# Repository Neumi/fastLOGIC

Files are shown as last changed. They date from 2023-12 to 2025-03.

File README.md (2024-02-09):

# fastLOGIC! open-source (industrial) logic controller
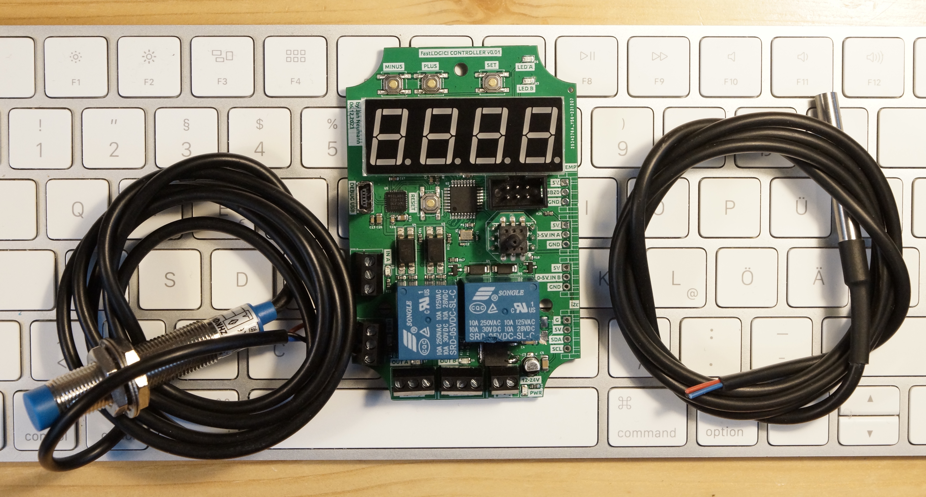
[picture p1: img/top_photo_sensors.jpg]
banner image


### An affordable Arduino-based board designed for straightforward (industrial) logic control, ideal for building small-scale automation and control solutions.
FastLOGIC! is designed to cater to the automation needs of various applications, especially those with modest logic requirements. Its purpose is to streamline smaller projects by eliminating the need for excessive error-prone breadboarding while retaining flexibility and adaptability.

Use cases could be one of these: 
- a programmable fridge controller
- water level-dependent pump controller
- a timer that is triggered by a button
- an actuator that activates and moves to an end stop upon receiving a triggering input
- some sensor data you need to display
- a water level sensor/alarm
- you get the idea

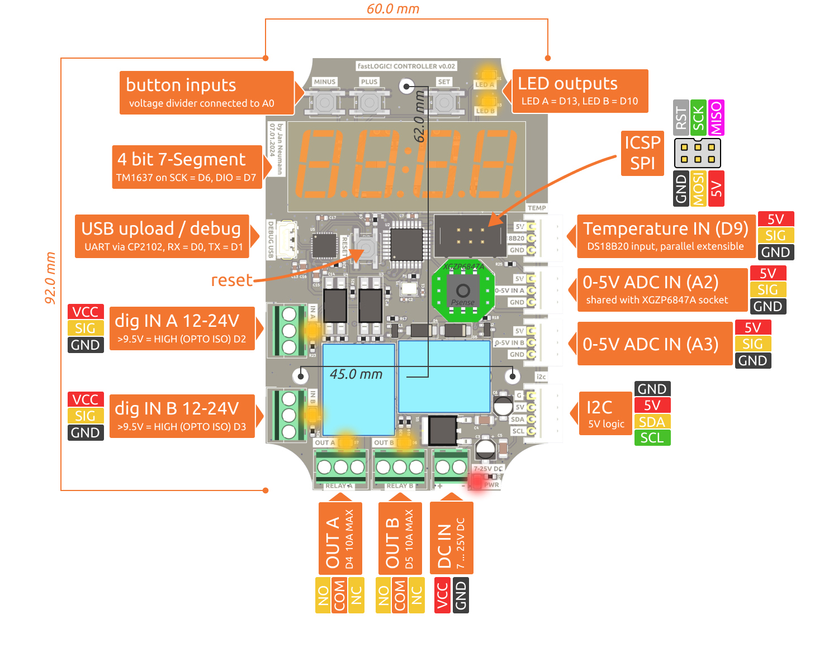
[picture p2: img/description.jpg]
description image


# Software

The Arduino [library](https://github.com/Neumi/fastLOGIC/tree/main/software/library/fastLOGIC) can be used to get started. A few example sketches show what fastLOGIC! is capable of, how to read sensor data and how to write outputs to the LEDs and relays.

The library covers most cases, but if you want to write or read directly from or to the pins:
```cpp
// fastLOGIC! pin mapping
DIGITAL_IN_A = D2;
DIGITAL_IN_B = D3;
RELAY_A_OUT = D5;
RELAY_B_OUT = D4;
TM1637_SCK = D6;
TM1637_DIO = D7;
DS18B20_DATA = D9;
LED_B_OUT = D10;
LED_A_OUT = D13;
VOLTAGE_SENS_IN = A0;
BUTTONS_IN = A1;
ANALOG_IN_A = A2;
ANALOG_IN_B = A3;
```

If you want to use the **7-segment display**, use this [library](https://github.com/avishorp/TM1637).

The part numbers in the KiCAD files are LCSC part numbers. This means you can order directly from JLCPCB using the manufacturing files in the [production folder](https://github.com/Neumi/fastLOGIC/tree/main/hardware/version001/fastLOGIC/production).
I typically opt for SMT parts exclusively due to the high cost associated with THT assembly and also because not all the required parts are readily available in stock.

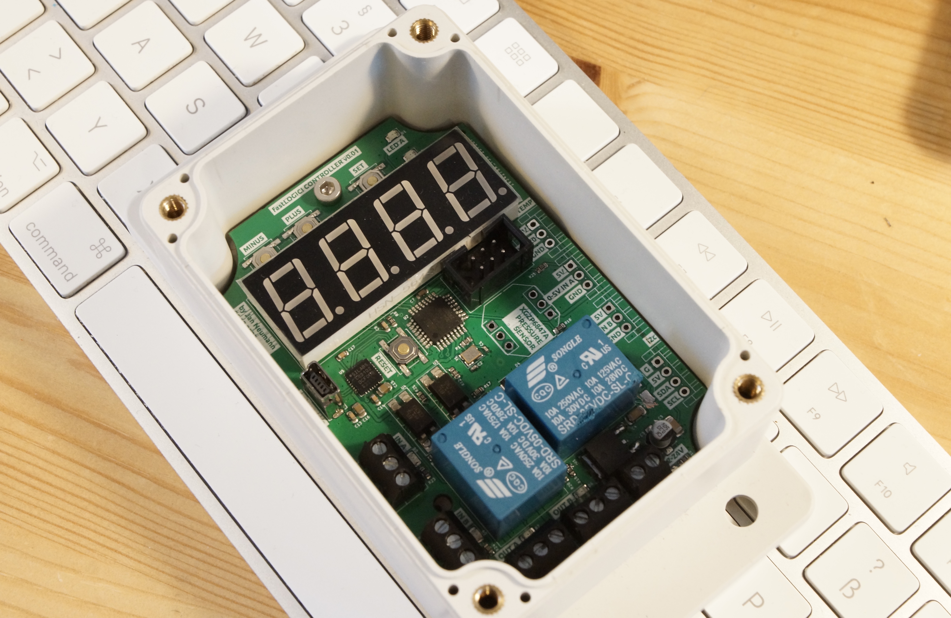
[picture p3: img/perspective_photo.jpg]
perspective photo


# Hardware
The placement is largely self-explanatory. If you find yourself uncertain, you can refer to the images provided below or utilize the 3D view feature in KiCAD for further clarification.

###  The only hardware parts you need:
- [relais 5V](https://de.aliexpress.com/item/1005006065653383.html)
- [4-bit Common Anode Display](https://de.aliexpress.com/item/1005006101748128.html)
- [JST connectors 3pin + 4pin](https://de.aliexpress.com/item/4000120545240.html)
- [Screw terminals 2pin + 3pin](https://de.aliexpress.com/item/1005005194957825.html)
- [USB connector Type A](https://de.aliexpress.com/item/1005004679855929.html)
- [Case](https://de.aliexpress.com/item/32760647473.html)
- an [ISP](https://de.aliexpress.com/item/1005006164091737.html) or Arduino in ISP mode to burn the Bootloader
- three 5mm (M3) screws

### Optional:
- [XGZP6847a pressure sensor](https://de.aliexpress.com/item/1005003768236942.html)
- [High-pressure sensor](https://de.aliexpress.com/item/1005005510454084.html)
- [DS18B20 temperature sensor](https://de.aliexpress.com/item/1005005973956237.html)

## Assembly
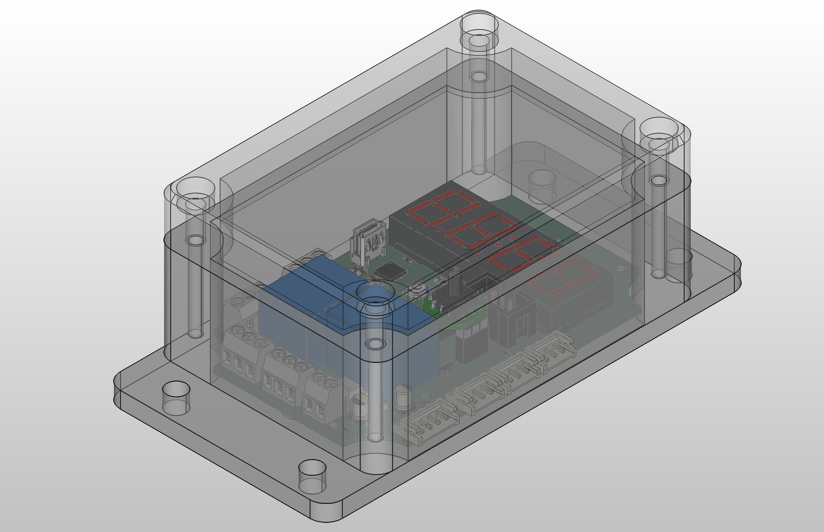
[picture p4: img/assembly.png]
assembly case 3D


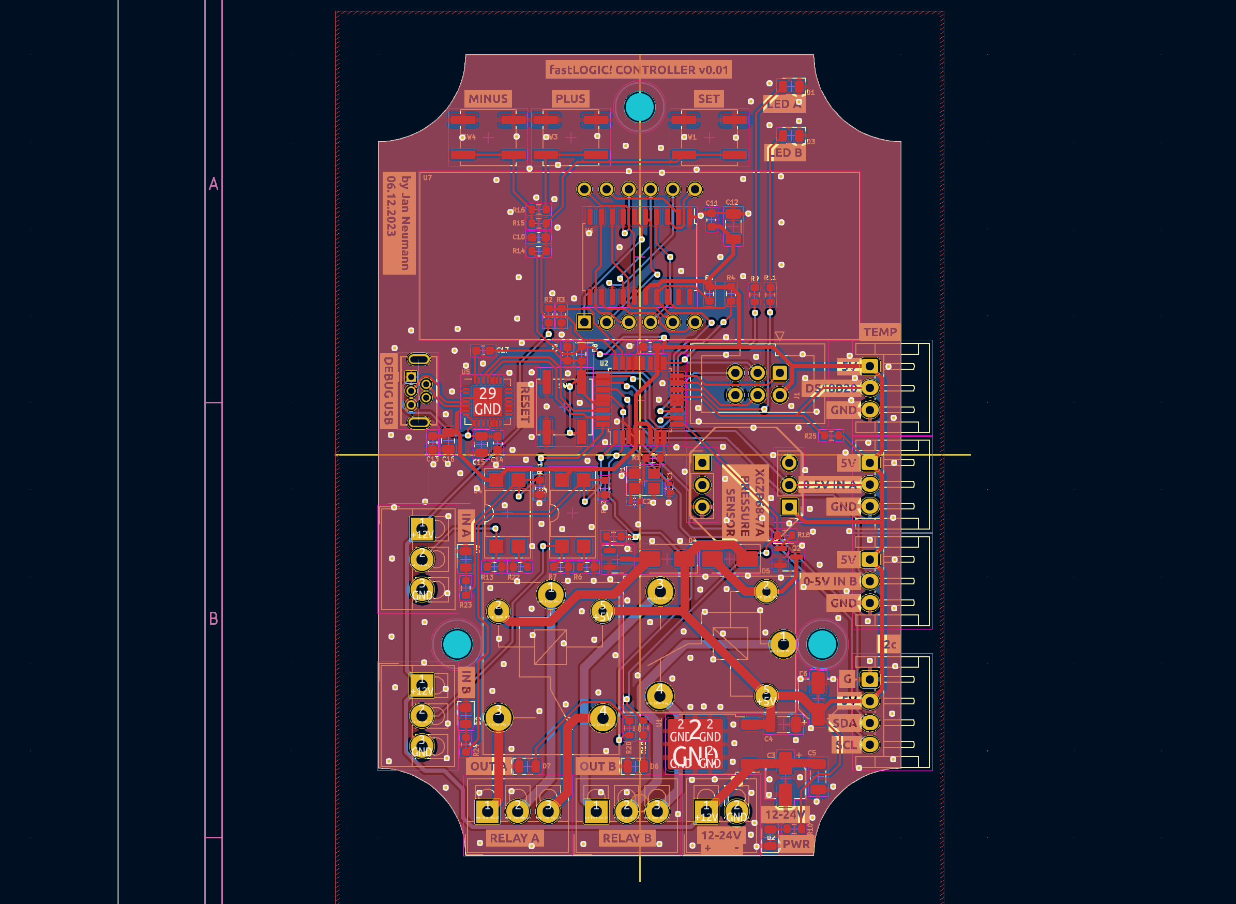
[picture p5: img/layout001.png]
layout screenshot


## Video:
LINK TO VIDEO (https://www.youtube.com/watch?v=e4RQ7bSTlrE)

Follow the project on [hackaday.io](https://hackaday.io/project/194762-fastlogic-open-source-industrial-logic-control)!

### Enjoy the project, but keep in mind:
* **The project is still under development and is currently in the prototype stage! Keep an eye out for updates!**
* **This also implies that not all functions are guaranteed to work flawlessly and may not be entirely safe**
* **Avoid unsupervised usage in a production environment. Utilize at your own risk**
* **Ensure input voltage is between the range of 12 to 25V. (Currently lacking reverse polarity protection)**
* **Do not use the relay to switch mains voltage! It's suitable only for low voltage and currents below 5A**

### Happy building + coding!

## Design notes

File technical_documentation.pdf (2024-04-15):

FastLOGIC! industrial controller technical documentation

FastLOGIC! industrial controller hardware revision 0.02_07.01.2024 document version 1.0

### Description

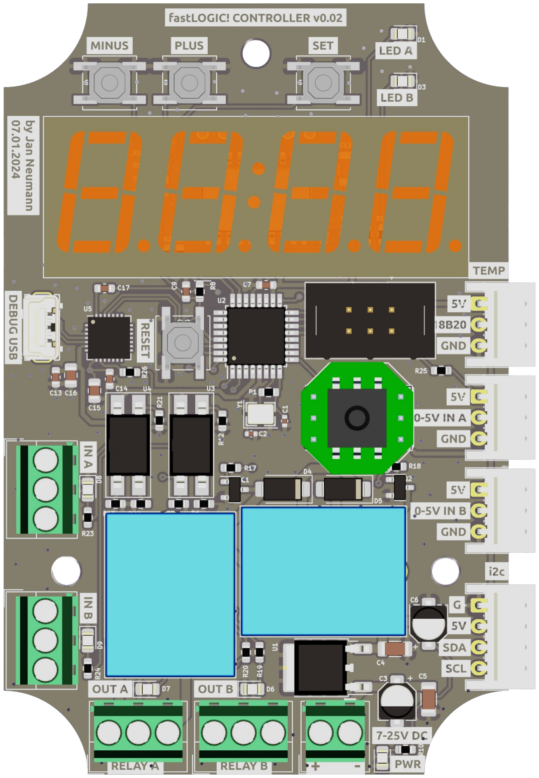
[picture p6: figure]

FastLOGIC! is a development board to get started with simple automation tasks. It could be used for experimentation and education but also for small permanent automation installations. A number of standard and easy-to-use in- and outputs give the user fast access to the world of automation.
Use cases could range from a simple sensor data display to complex logic operations and decision-making based on sensor inputs to switch outputs.

### Target users

Makers, Hobbyists, Engineers

FastLOGIC! v0.02

### Features

- ATMega328p microcontroller
- AVR CPU at 16MHz
- 32KB Flash
- 2KB SRAM
- 1KB EEPROM
- Power
- 7-25V DC supply
- 5V logic and sensor voltage
- 34mA idle current at 12V
- Peripherals I/O
- USB / UART
- 2x digital input
- 3x button input
- 2x orange LED output
- 4-Bit 7-Segment red display
- DS18b20 temperature sensor
- XGZP6847A pressure sensor socket
- 2x 10-Bit 0-5V analog input
- I2C interface
- Serial Peripheral Interface (SPI)
- 2x relay output
- Watchdog timer
- Electrical connectors
- Mini USB vertical
- 3.5mm screw terminal for relays and digital inputs (3-pin)
- 3.5mm screw terminal for power (2-pin)
- JST EH sensor inputs (3-pin)
- JST EH i2C (4-pin)
- XGZP6847A pressure sensor socket
- 6-pin ICSP programming header
- Physical properties
- PCB only: 90 * 60 * 19 mm (L * W * H), 43g
- With Housing: 100 * 68 * 50 mm (L * W * H), 98g
- M3 mounting: triangle 45 * 62 mm (A * h)
- Software
- Programmable via Arduino IDE
- FastLOGIC! library

Page 2

### 1 Application Examples and Use Cases

For educational, hobby, and professional users FastLOGIC! provides an easy start to automation as the well-known programming language C++ and the Arduino IDE can be used out of the box. Everything that runs on an Arduino UNO runs on FastLOGIC! as well.
Standard sensors and interfaces make FastLOGIC! easily adaptable and expandable.

Possible use cases could be:
- display to read sensor data
- a timer that switches an output for a defined time after a button press
- RPM counter using an induction sensor
- water level sensor using the XGZP6847A pressure sensor
- temperature controller using DS18b20 sensors with EEPROM set value data memory

### 2 Ratings

Symbol | Description | Min | Typ | Max | Unit
Vin | Input supply voltage on screw terminal | 7.0 | 12.0 | 25.0 | V
U | Current draw at 12V input voltage | 0.04 | - | 0.3 | A
P | Power consumption at 12V | 0.4 | - | 3.6 | W
Vusb | USB supply voltage | 4.5 | 5.0 | 5.5 | V
Urel | Switchable relay current | - | - | 10 | A
Irel | Switchable relay voltage | - | - | 30 | V
Vtrig | Digital input A and B trigger voltage | - | 9.5 | - | V
Vanalog | Analog input voltage | -0.5 | - | 5.5 | V
Tmax | Safe temperature range | -40 | - | +85 | °C

NOTE: In extreme temperatures, EEPROM, voltage regulator, analog reference, and the crystal oscillator, might not work as expected!

Page 3

### 3 Functional Overview

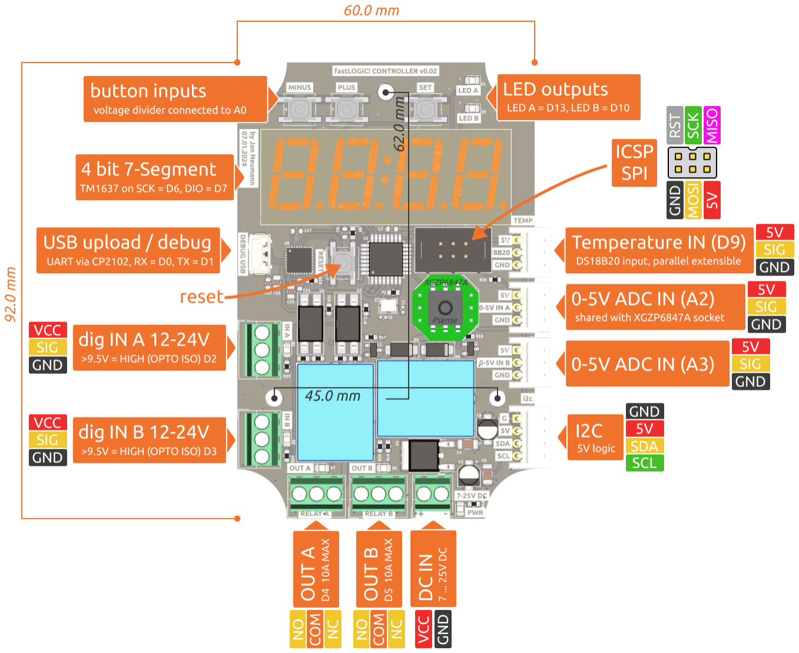
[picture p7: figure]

Figure 1: Functional overview of inputs, outputs, dimensions, and pinouts

### 4 Getting Started Connect

To program the board using the Arduino IDE, use a Mini USB cable to connect it to the computer. The cable also provides 5V power to run the board.

NOTE: The computer must provide enough current to power all connected sensors!

Page 4

### IDE Setup

The board behaves just like an Arduino UNO board. Therefore select Ardunino UNO as the development platform. The board has to be “Arduino Uno”. Select the corresponding serial port for your board.

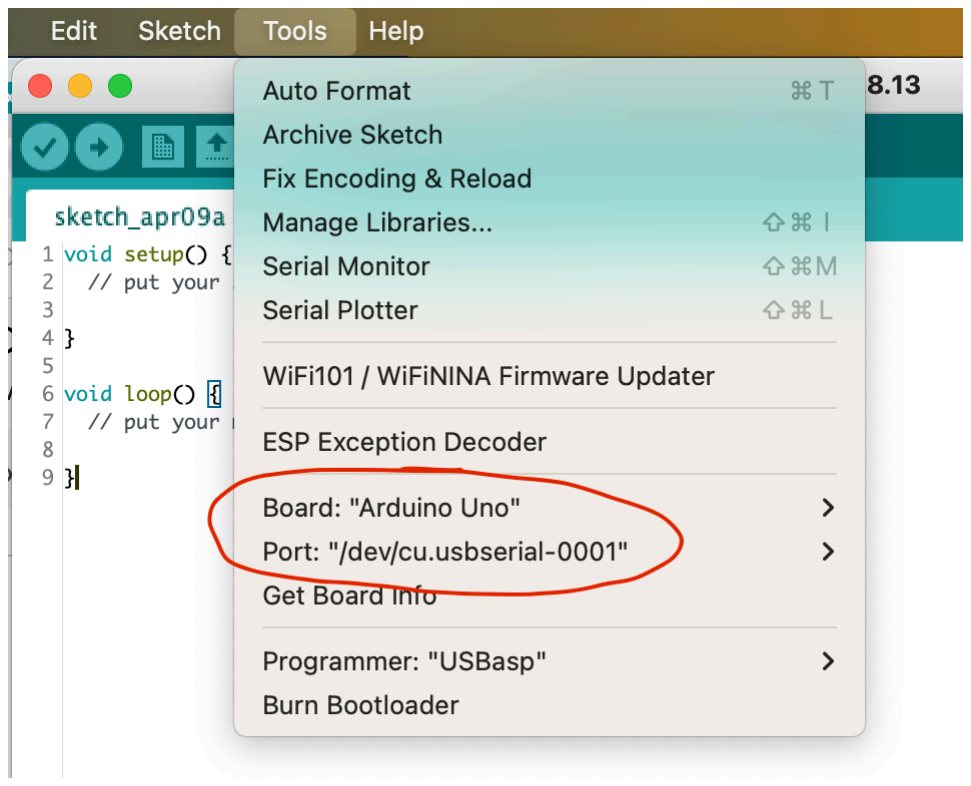
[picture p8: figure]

Figure 2: Arduino IDE board settings for uploading code to FastLOGIC!

Use the upload button to upload the code.

Note: Press the reset button on FastLOGIC! while the code is uploading. Otherwise, the upload will fail.

### Programming

Use the examples from the GitHub repository to get started. It helps you use the ports, sensors, and relays with simple OOP methods.
You can use all the standard functionalities, the Arduino UNO supports like millis, sleep, EEPROM, etc. Inputs can be read using digitalRead and analogRead. The relays can be switched using digitalWrite on the corresponding pins.

Page 5

### Pin mapping

Each functionality is connected to a certain pin on the ATMega328. The pin mapping shows each pin and its associated function.

Page 6

Pin name | Pin number | Description
RX | D0 | directly connected to CP2102 USB / Serial chip
TX | D1 | directly connected to CP2102 USB / Serial chip
DIGITAL_IN_A | D2 | reads HIGH when input A HIGH (>9.5V)
DIGITAL_IN_B | D3 | reads HIGH when input B HIGH (>9.5V)
RELAY_B_OUT | D4 | output HIGH drives the relay B
RELAY_A_OUT | D5 | output HIGH drives the relay A
TM1637_SCK | D6 | TM1637 display driver clock pin
TM1637_DIO | D7 | TM1637 display driver data pin
NC | D8 | not connected
DS18B20_DATA | D9 | DS18B20 temperature sensor data pin (pulled HIGH by 4.7k)
LED_B_OUT | D10 | HIGH enables LED B
LED_A_OUT | D13 | HIGH enables LED A
VOLTAGE_SENS_IN | A0 | reads Vin via 1 : 4.45 voltage divider (Vin 25V MAX!)
BUTTONS_IN | A1 | reads buttons: SET: <20; MINUS: >25 & <45; PLUS: >320 & <470
ANALOG_IN_A | A2 | reads analog IN A and XGZP6847A pressure sensor
ANALOG_IN_B | A3 | reads analog IN B 0-5V (5.5V MAX!)
I2C_SDA | A4 | I2C bus data pin SDA
I2C_SCL | A5 | I2C bus clock pin SCL

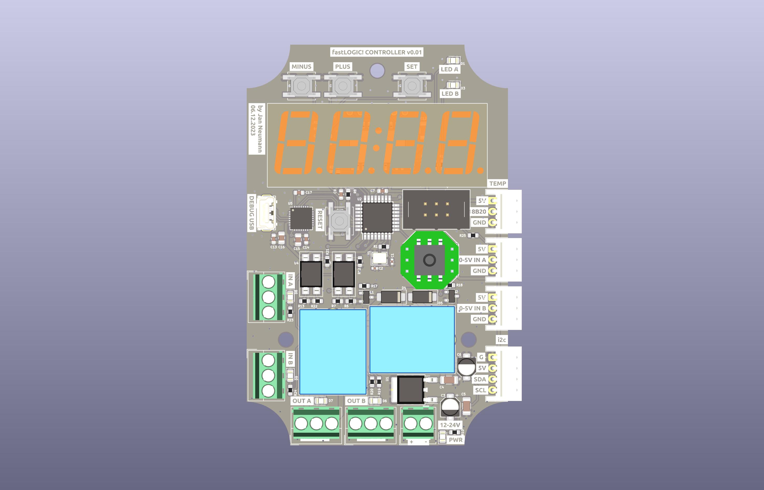
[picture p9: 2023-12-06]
img/board001.png

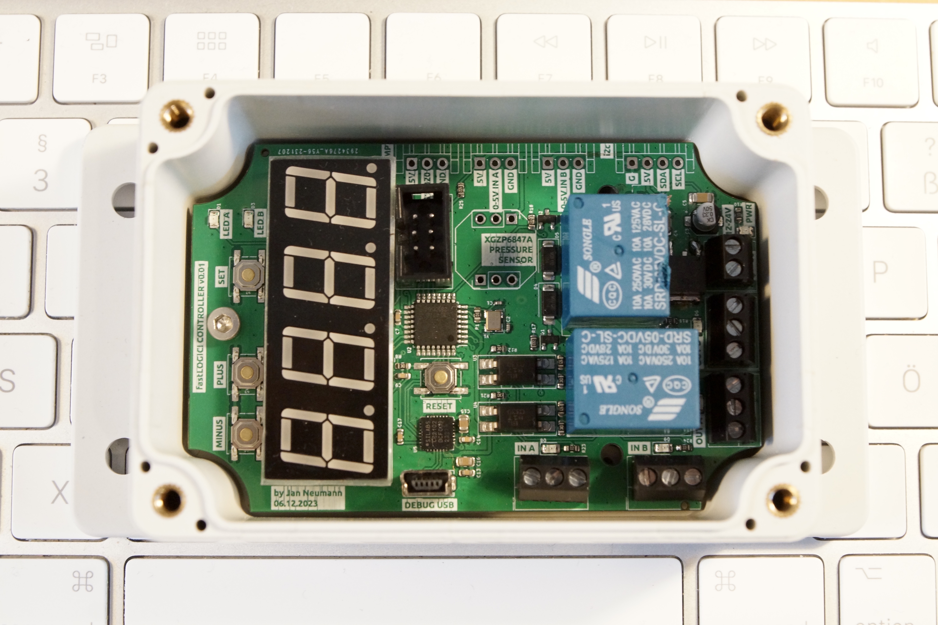
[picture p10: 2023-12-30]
img/top_photo.jpg

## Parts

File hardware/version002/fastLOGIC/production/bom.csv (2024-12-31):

Designator | Footprint | Quantity | Value | LCSC Part #
BT1 | BatteryHolder_Keystone_1060_1x2032 | 1 | Battery_Cell | C70377
C1, C12 | 1206 | 2 | C100uF | C15008
C10, C11, C13, C14, C15, C16, C17, C19, C2, C23, C24, C27, C31, C7, C8, C9 | 0603 | 16 | C100nF | C14663
C18, C4, C5 | 1206 | 3 | C100nF | C24497
C20, C21 | 0402 | 2 | C22pF | C1555
C22, C6 | 1206 | 2 | C47uF | C96123
C28 | 1206 | 1 | C1nF | C9196
C29, C30 | 0402 | 2 | C18pF | C1549
C3 | CP_Elec_4x5.4 | 1 | C_330nF | C264238
C32, C45 | 0805 | 2 | C10uF | C15850
C33 | 0402 | 1 | C10nF | C15195
C34 | 0603 | 1 | C22nF | C21122
C35 | 0402 | 1 | C4.7uF | C23733
C36 | 0603 | 1 | C10nF | C57112
C37, C38 | 0402 | 2 | C6.8nF | C1542
C39, C40, C41, C42, C43, C44 | 0402 | 6 | C100nF | C307331
D1 | 0805 | 1 | LED_A | C2297
D10 | 0805 | 1 | LED_SPD | C2296
D11 | 0805 | 1 | LED_3.3V_PWR | C2296
D12 | 0805 | 1 | LED_DUP | C2296
D13 | 0805 | 1 | LED_PC13 | C84256
D14 | 0805 | 1 | LED_OUT_C | C2296
D15, D4, D5 | D_SMA | 3 | D | C22452
D16 | 0805 | 1 | LED_C | C2297
D17 | 0805 | 1 | LED_D | C2297
D18 | 0805 | 1 | TX | C2297
D19 | 0805 | 1 | RX | C2297
D2 | 0805 | 1 | LED_PWR | C84256
D3 | 0805 | 1 | LED_B | C2297
D6, D9 | 0805 | 2 | LED_OUT_B | C2296
D7, D8 | 0805 | 2 | LED_OUT_A | C2296
H1, H2, H3, H5 | MountingHole_3.2mm_M3_DIN965 | 4 | MH
J1 | JST_EH_S3B-EH_1x03_P2.50mm_Horizontal | 1 | 0-5V_ANALOG_IN_A | C157928
J10 | LCD_GMG12864-06D | 1 | LCD
J11, J19, J24 | PinHeader_1x02_P2.54mm_Vertical | 3 | GND
J12, J18, J20 | Jack_3.5mm_PJ320E_Horizontal | 3 | AudioJack4_Ground
J13 | JST_EH_S3B-EH_1x03_P2.50mm_Horizontal | 1 | 0-5V_ANALOG_IN_B | C157928
J14 | TerminalBlock_4Ucon_1x03_P3.50mm_Vertical | 1 | RELAY_OUT_B | C2997510
J15 | TerminalBlock_4Ucon_1x03_P3.50mm_Vertical | 1 | RELAY_OUT_A | C2997510
J16 | TerminalBlock_4Ucon_1x03_P3.50mm_Vertical | 1 | RELAY_OUT_C | C2997510
J17 | USB_Mini-B_Tensility_54-00023_Vertical | 1 | USB_B_Mini | C6331167
J2 | TerminalBlock_4Ucon_1x02_P3.50mm_Vertical | 1 | RS485 | C2997509
J21 | microSD_HC_Hirose_DM3AT-SF-PEJM5 | 1 | Micro_SD_Card_Det_Hirose_DM3AT | C114218
J22, J25, J6 | PinHeader_1x02_P2.54mm_Vertical | 3 | VIN
J23 | RJ45_Hanrun_HR911105A_Horizontal | 1 | HR911105A | C12074
J26 | JST_EH_B4B-EH-A_1x04_P2.50mm_Vertical | 1 | UART | C157925
J3 | JST_EH_S3B-EH_1x03_P2.50mm_Horizontal | 1 | DS18B20 | C157928
J4 | TerminalBlock_4Ucon_1x02_P3.50mm_Vertical | 1 | 12-24V | C2997509
J5 | JST_EH_S4B-EH_1x04_P2.50mm_Horizontal | 1 | I2C | C157925
J8 | TerminalBlock_4Ucon_1x03_P3.50mm_Vertical | 1 | 12-24V_IN_A | C2997510
J9 | TerminalBlock_4Ucon_1x03_P3.50mm_Vertical | 1 | 12-24V_IN_B | C2997510
JP1, JP2 | PinHeader_1x02_P2.54mm_Vertical | 2 | termination_jumper
K1, K2, K3 | Relay_SPDT_SANYOU_SRD_Series_Form_C | 3 | SANYOU_SRD_Form_C | C35449
L1 | 0805 | 1 | L600OHM | C1017
Q1, Q2, Q3, Q6 | SOT-23 | 4 | MMBT5551L | C2145
Q4, Q5 | SOT-23 | 2 | BSS138 | C112239
R1, R10, R11, R19, R2, R20, R23, R24, R44, R45, R53, R54, R63, R64, R65, R66, R9 | 0603 | 17 | R330 | C23138
R12, R13, R14, R15, R16, R21, R26, R31, R33, R34, R36, R37, R39, R4, R5, R59, R7 | 0603 | 17 | R10k | C25804
R17, R18, R3, R60 | 0603 | 4 | R2.2k | C4190
R22, R6 | 0603 | 2 | R470 | C23179
R25 | 0603 | 1 | R4.7k | C23162
R27 | 0805 | 1 | R120 | C17437
R28, R38 | 0402 | 2 | R1M | C26083
R29, R30, R32, R35, R48, R55, R56, R57, R58, R61, R62, R8 | 0603 | 12 | R1k | C21190
R40, R41, R42, R43 | 0603 | 4 | R33 | C23140
R46 | 0603 | 1 | R12K4 | C22865
R47 | 0603 | 1 | R10 | C22859
R49, R50, R51, R52 | 0603 | 4 | R49.9 | C23185
SW1 | SW_Push_1P1T_NO_CK_KSC7xxJ | 1 | SET | C318884
SW3 | SW_Push_1P1T_NO_CK_KSC7xxJ | 1 | PLUS | C318884
SW4 | SW_Push_1P1T_NO_CK_KSC7xxJ | 1 | MINUS | C318884
SW5 | SW_Push_1P1T_NO_CK_KSC7xxJ | 1 | RST | C318884
TP1 | TestPoint_Pad_D2.0mm | 1 | PA4
TP2 | TestPoint_Pad_D2.0mm | 1 | SCL2
TP3 | TestPoint_Pad_D2.0mm | 1 | RX
TP4 | TestPoint_Pad_D2.0mm | 1 | TX
TP5, TP8 | TestPoint_Pad_D2.0mm | 2 | GND
TP6, TP9 | TestPoint_Pad_D2.0mm | 2 | 3.3V
TP7 | TestPoint_Pad_D2.0mm | 1 | SDA2
U1 | TO-252-2 | 1 | LM78M05_TO252 | C58069
U10 | SOT-223-3_TabPin2 | 1 | AMS1117-3.3 | C6186
U13 | LQFP-48_7x7mm_P0.5mm | 1 | W5500 | C32843
U2 | XGZP6847A | 1 | ~
U3, U4 | DIP-4_W8.89mm_SMDSocket_LongPads | 2 | EL817 | C106900
U6 | LQFP-100_14x14mm_P0.5mm | 1 | STM32F407VGTx | C12345
U8 | SOP-8_3.9x4.9mm_P1.27mm | 1 | MAX485E | C481667
U9 | QFN-28-1EP_5x5mm_P0.5mm_EP3.35x3.35mm | 1 | CP2102N-A01-GQFN28 | C6568
Y2 | Crystal_SMD_5032-2Pin_5.0x3.2mm | 1 | Crystal | C115962
Y3 | Crystal_SMD_3225-4Pin_3.2x2.5mm | 1 | Crystal_25MHz | C9006

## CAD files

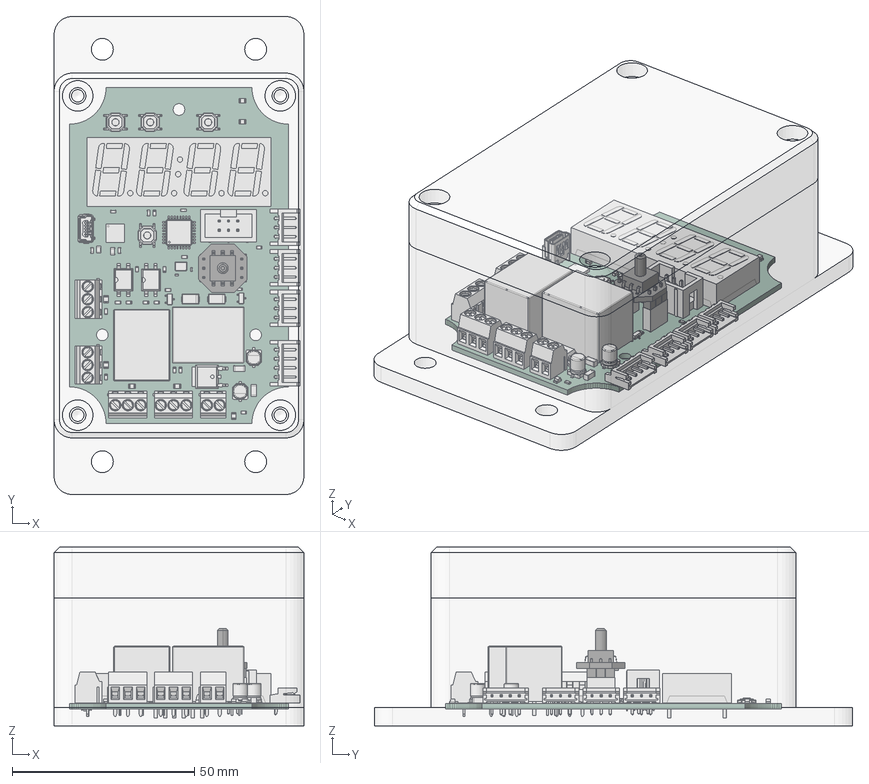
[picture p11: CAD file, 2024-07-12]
hardware/full_assembly.FCStd
68.5 x 131.0 x 49.0 mm
case
PCB
lid

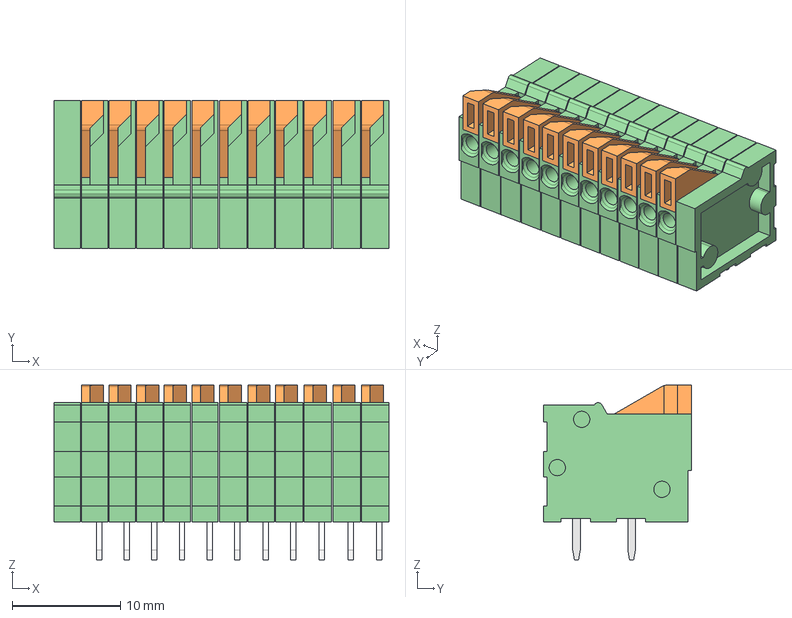
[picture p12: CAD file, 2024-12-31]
hardware/version002/fastLOGIC/3d_files/TERMINAL_BLOCKS_141r/DG141R-11-2.54.step
30.9 x 13.6 x 16.1 mm
Тело_28 - Копия_3:4 x 5
Тело_28 - Копия_3:3 x 5
Тело_28 - Копия_3:2 x 5
Тело_28 - Копия_3:1 x 5
Тело_11 - Внешняя модель_11:2 x 2
Тело_12 - Внешняя модель_12:2 x 2
Тело_20 - Внешняя модель_20:2 x 2
Тело_14 - Внешняя модель_14:2 x 2

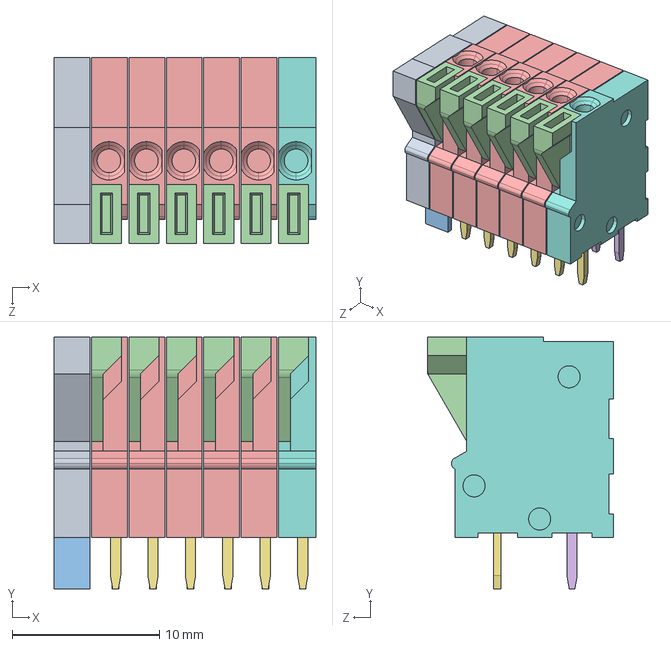
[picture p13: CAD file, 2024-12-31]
hardware/version002/fastLOGIC/3d_files/TERMINAL_BLOCKS_141v/DG141V-5-2.54.STEP
17.8 x 17.1 x 12.6 mm

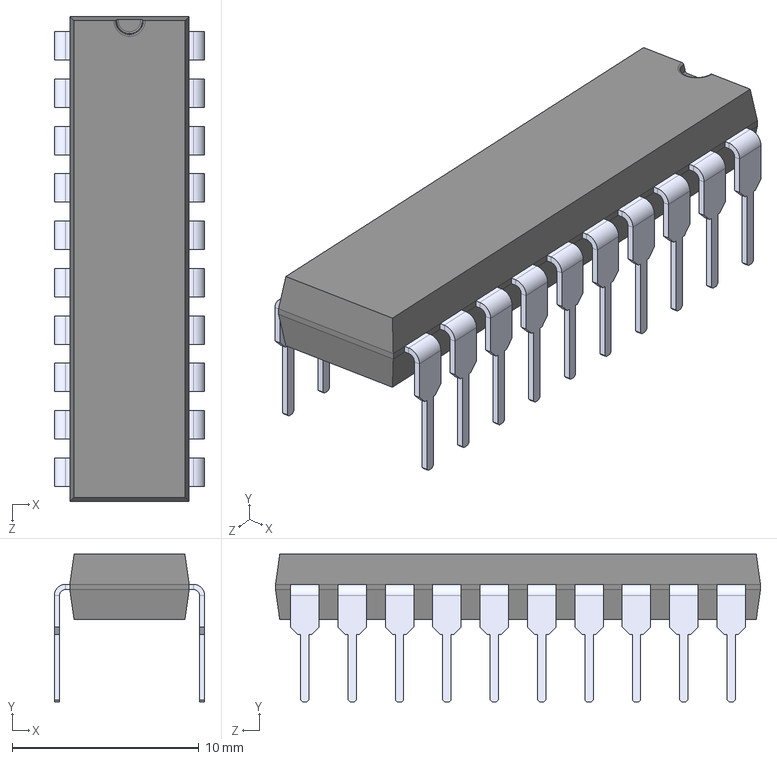
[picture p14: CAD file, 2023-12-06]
hardware/version002/fastLOGIC/components/TM1637/TM1637.step
8.06 x 7.91 x 26.0 mm

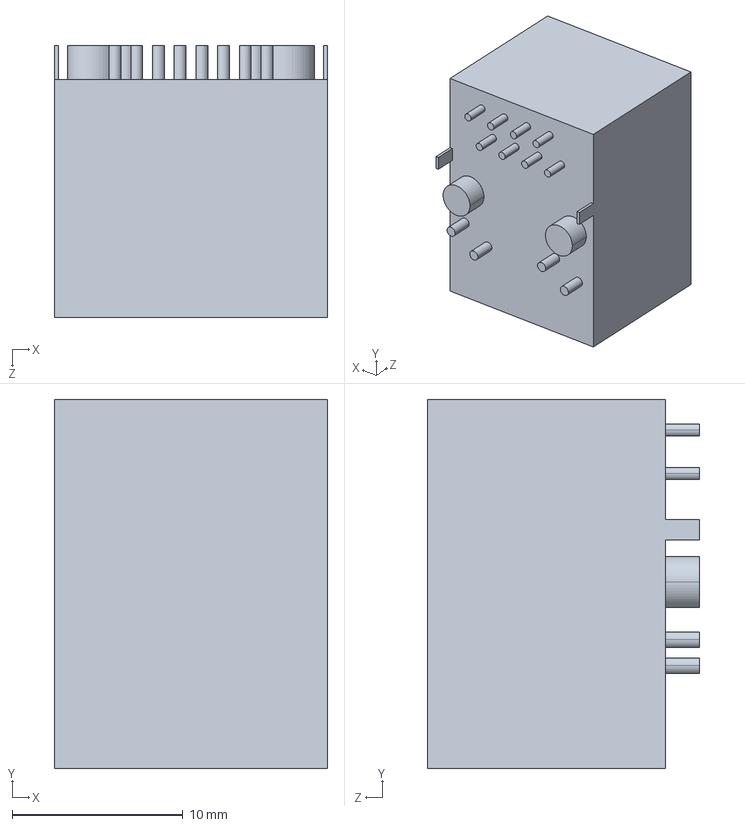
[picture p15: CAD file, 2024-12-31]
hardware/version002/fastLOGIC/3d_files/HANRUN.STEP
16.0 x 21.6 x 15.9 mm

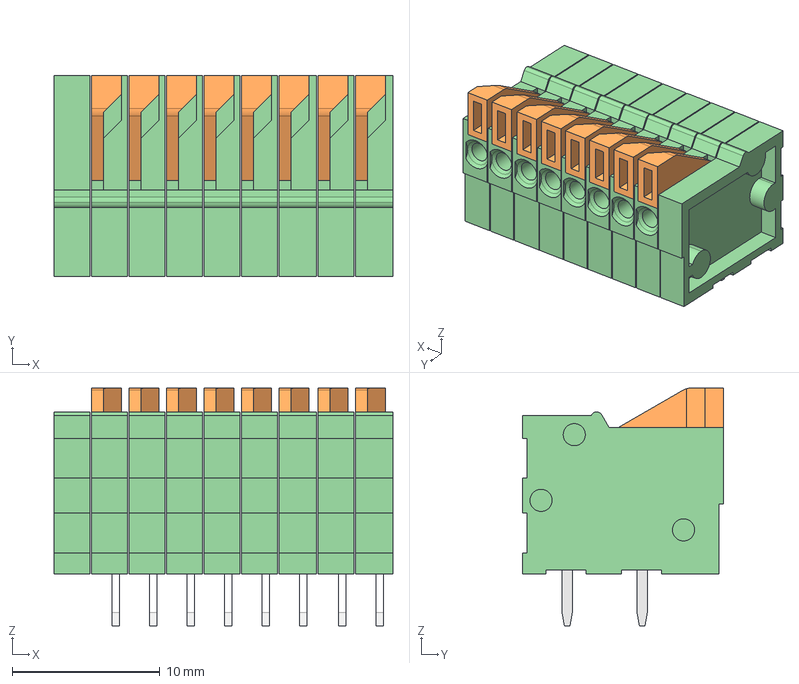
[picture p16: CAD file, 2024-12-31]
hardware/version002/fastLOGIC/3d_files/TERMINAL_BLOCKS_141r/DG141R-8-2.54.step
23.0 x 13.6 x 16.1 mm
Тело_1 - Внешняя модель_1:2 x 2
Тело_11 - Внешняя модель_11:2 x 2
Тело_12 - Внешняя модель_12:2 x 2
Тело_6 - Внешняя модель_6:2 x 2
Тело_19 - Внешняя модель_19:2 x 2
Тело_20 - Внешняя модель_20:2 x 2
Тело_14 - Внешняя модель_14:2 x 2
Тело_13 - Внешняя модель_13:2 x 2

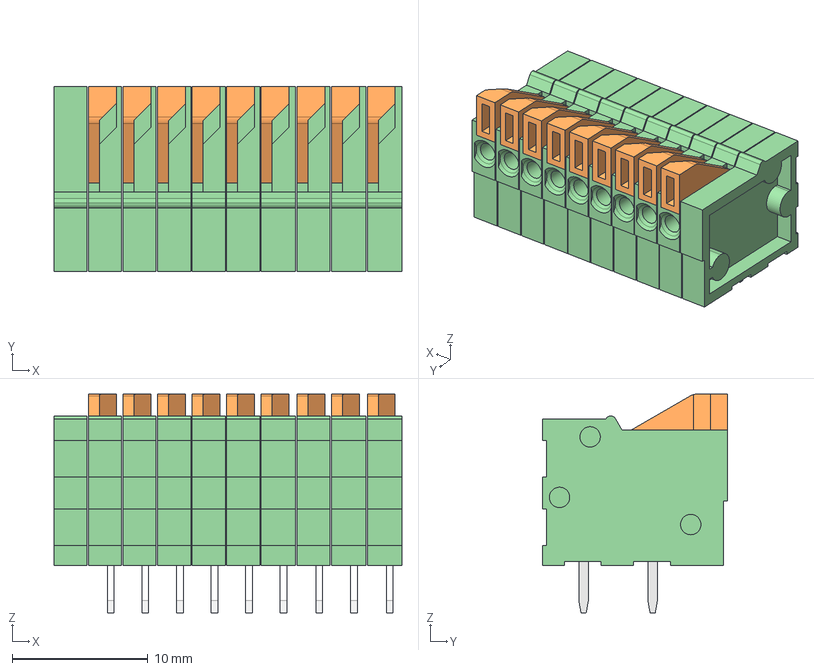
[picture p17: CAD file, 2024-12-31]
hardware/version002/fastLOGIC/3d_files/TERMINAL_BLOCKS_141r/DG141R-9-2.54.step
25.6 x 13.6 x 16.1 mm
Тело_1 - Внешняя модель_1:3 x 3
Тело_6 - Внешняя модель_6:3 x 3
Тело_13 - Внешняя модель_13:3 x 3
Тело_19 - Внешняя модель_19:3 x 3
Тело_11 - Внешняя модель_11:2 x 2
Тело_12 - Внешняя модель_12:2 x 2
Тело_20 - Внешняя модель_20:2 x 2
Тело_14 - Внешняя модель_14:2 x 2

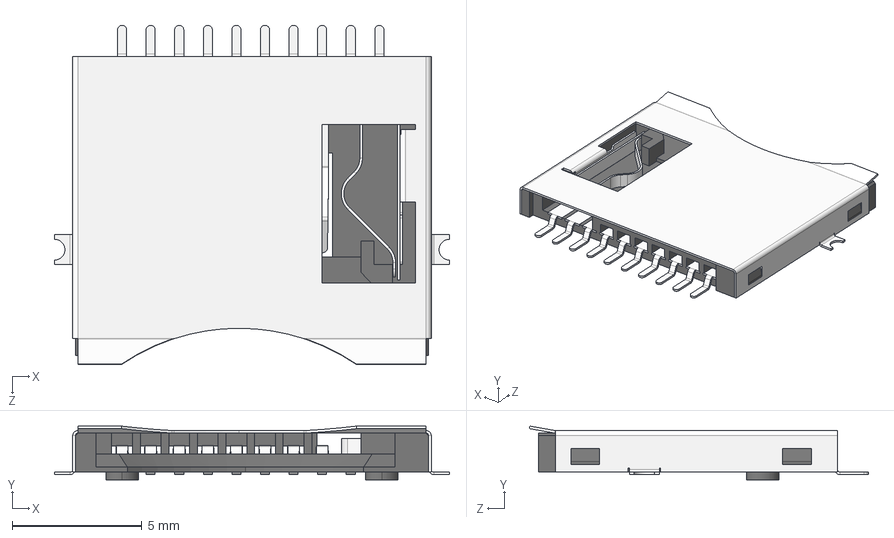
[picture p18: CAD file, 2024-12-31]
hardware/version002/fastLOGIC/3d_files/SocketMicroSD.STEP
15.2 x 2.07 x 13.1 mm
Base
Terminal 01 x 8
Terminal 02
Terminal 03
Socket Cover

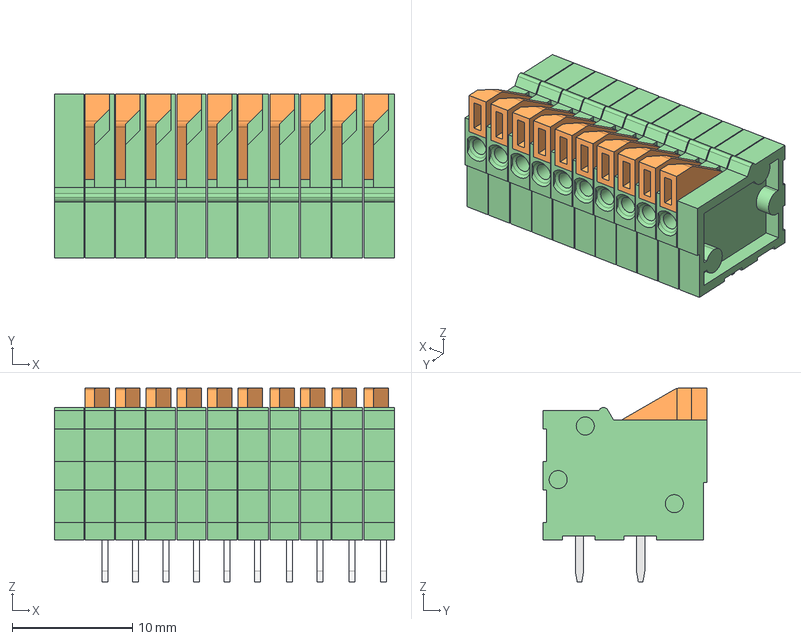
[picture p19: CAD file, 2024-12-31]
hardware/version002/fastLOGIC/3d_files/TERMINAL_BLOCKS_141r/DG141R-10-2.54.step
28.2 x 13.6 x 16.1 mm
Тело_27 - Копия_2:4 x 4
Тело_27 - Копия_2:3 x 4
Тело_27 - Копия_2:2 x 4
Тело_27 - Копия_2:1 x 4
Тело_11 - Внешняя модель_11:2 x 2
Тело_12 - Внешняя модель_12:2 x 2
Тело_20 - Внешняя модель_20:2 x 2
Тело_14 - Внешняя модель_14:2 x 2

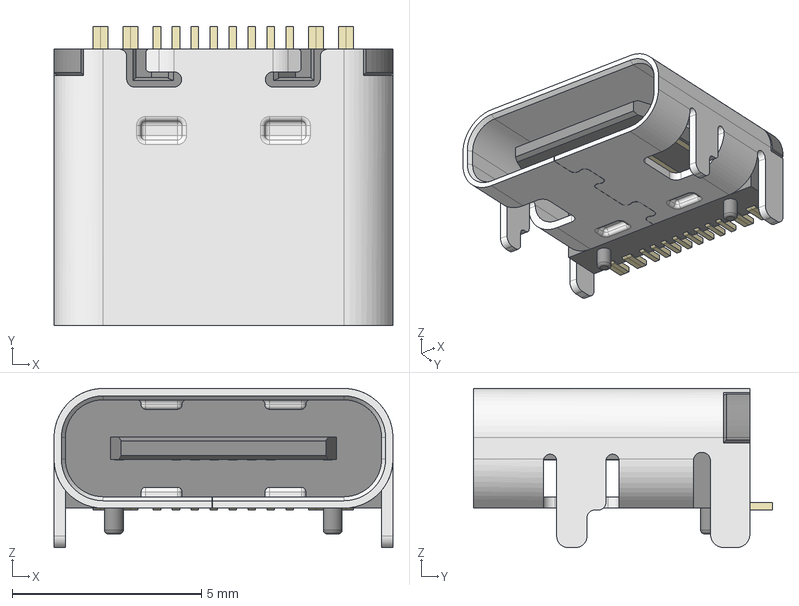
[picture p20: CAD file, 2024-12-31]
hardware/version002/fastLOGIC/3d_files/HRO_TYPE-C-31-M-12.step
8.95 x 7.90 x 4.20 mm

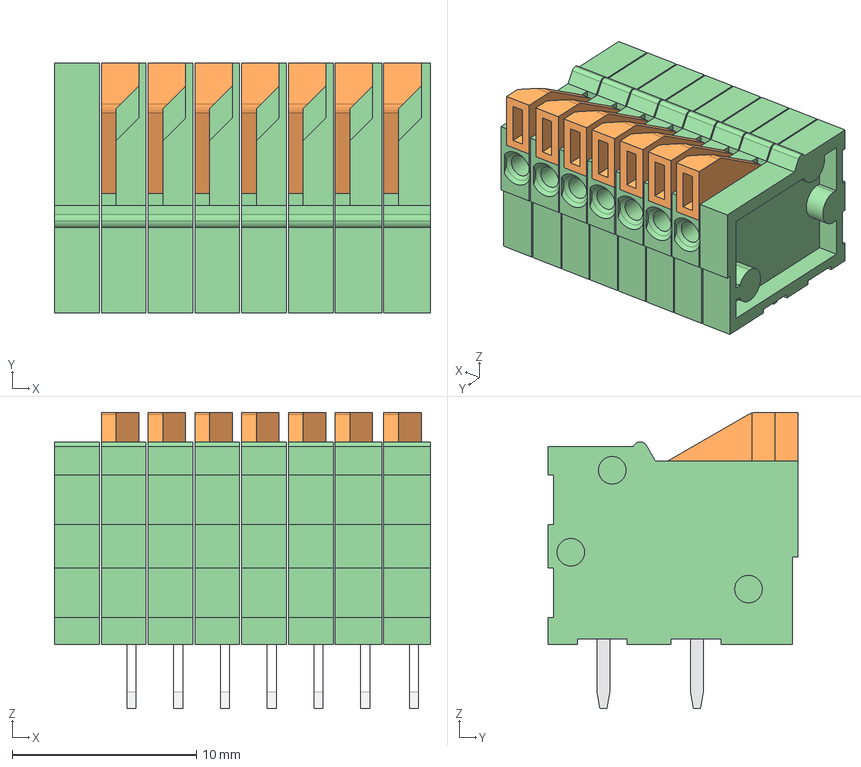
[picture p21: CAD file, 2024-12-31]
hardware/version002/fastLOGIC/3d_files/TERMINAL_BLOCKS_141r/DG141R-7-2.54.step
20.4 x 13.6 x 16.1 mm
Тело_1 - Внешняя модель_1:2 x 2
Тело_6 - Внешняя модель_6:2 x 2
Тело_13 - Внешняя модель_13:2 x 2
Тело_19 - Внешняя модель_19:2 x 2

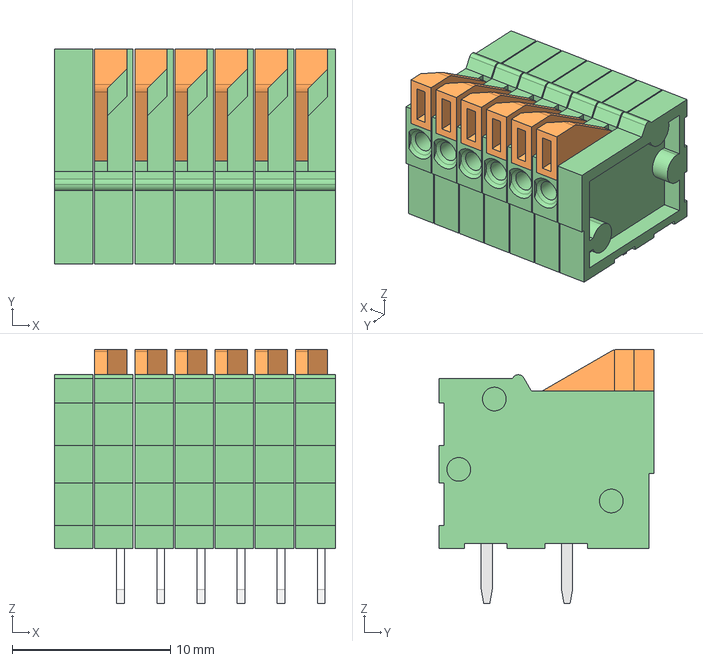
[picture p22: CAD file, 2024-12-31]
hardware/version002/fastLOGIC/3d_files/TERMINAL_BLOCKS_141r/DG141R-6-2.54.step
17.8 x 13.6 x 16.1 mm

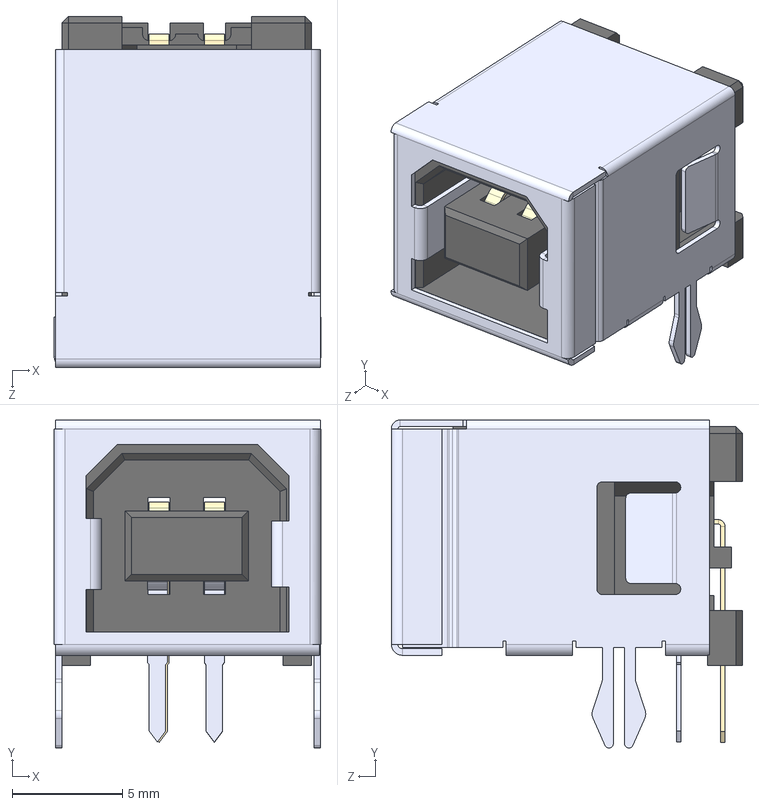
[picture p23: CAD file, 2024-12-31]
hardware/version002/fastLOGIC/3d_files/USB_B.STEP
12.1 x 14.8 x 15.9 mm
BlackBase
MetalShape
TermLong x 2
TermShort x 2

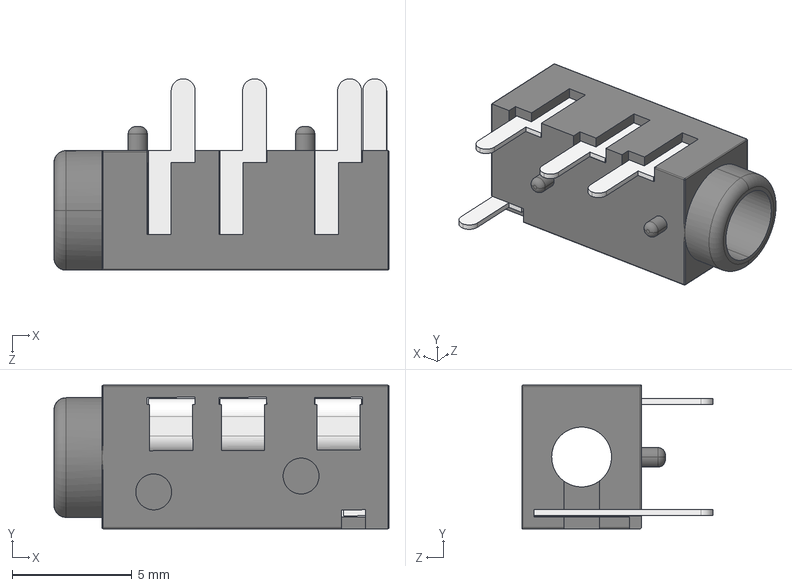
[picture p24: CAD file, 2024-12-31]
hardware/version002/fastLOGIC/3d_files/PJ320A.STEP
14.0 x 6.00 x 8.00 mm
PJ320A
PJ320A-Pin x 3
PJ320A-Pin-B

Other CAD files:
hardware/version002/fastLOGIC/3d_files/TERMINAL_BLOCKS_141v/DG141V-4-2.54.STEP
hardware/version002/fastLOGIC/3d_files/TERMINAL_BLOCKS_141v/DG141V-6-2.54.STEP
hardware/version002/fastLOGIC/3d_files/TERMINAL_BLOCKS_141v/DG141V-2-2.54.STEP
hardware/version002/fastLOGIC/3d_files/TERMINAL_BLOCKS_141v/DG141V-3-2.54.STEP
hardware/version002/fastLOGIC/3d_files/GMG12864-06D.step
hardware/version002/fastLOGIC/3d_files/HR911105A.step
hardware/version002/fastLOGIC/3d_files/Mini-B USB Vertical.stp
hardware/version002/fastLOGIC/3d_files/PCB Terminal Block 2 DEG381-3.5.step
hardware/version002/fastLOGIC/3d_files/PCB Terminal Block 3 DEG381-3.5.step
hardware/version002/fastLOGIC/3d_files/TERMINAL_BLOCKS_141r/DG141R-12-2.54.step
hardware/version002/fastLOGIC/3d_files/TERMINAL_BLOCKS_141r/DG141R-2-2.54.step
hardware/version002/fastLOGIC/3d_files/TERMINAL_BLOCKS_141r/DG141R-3-2.54.step
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

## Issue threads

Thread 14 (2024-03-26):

rework settings menu

Neumi, 2024-03-26:
Change settings menu 3-add-library-support-for-settings-menu so that it follows Arduino Class schema

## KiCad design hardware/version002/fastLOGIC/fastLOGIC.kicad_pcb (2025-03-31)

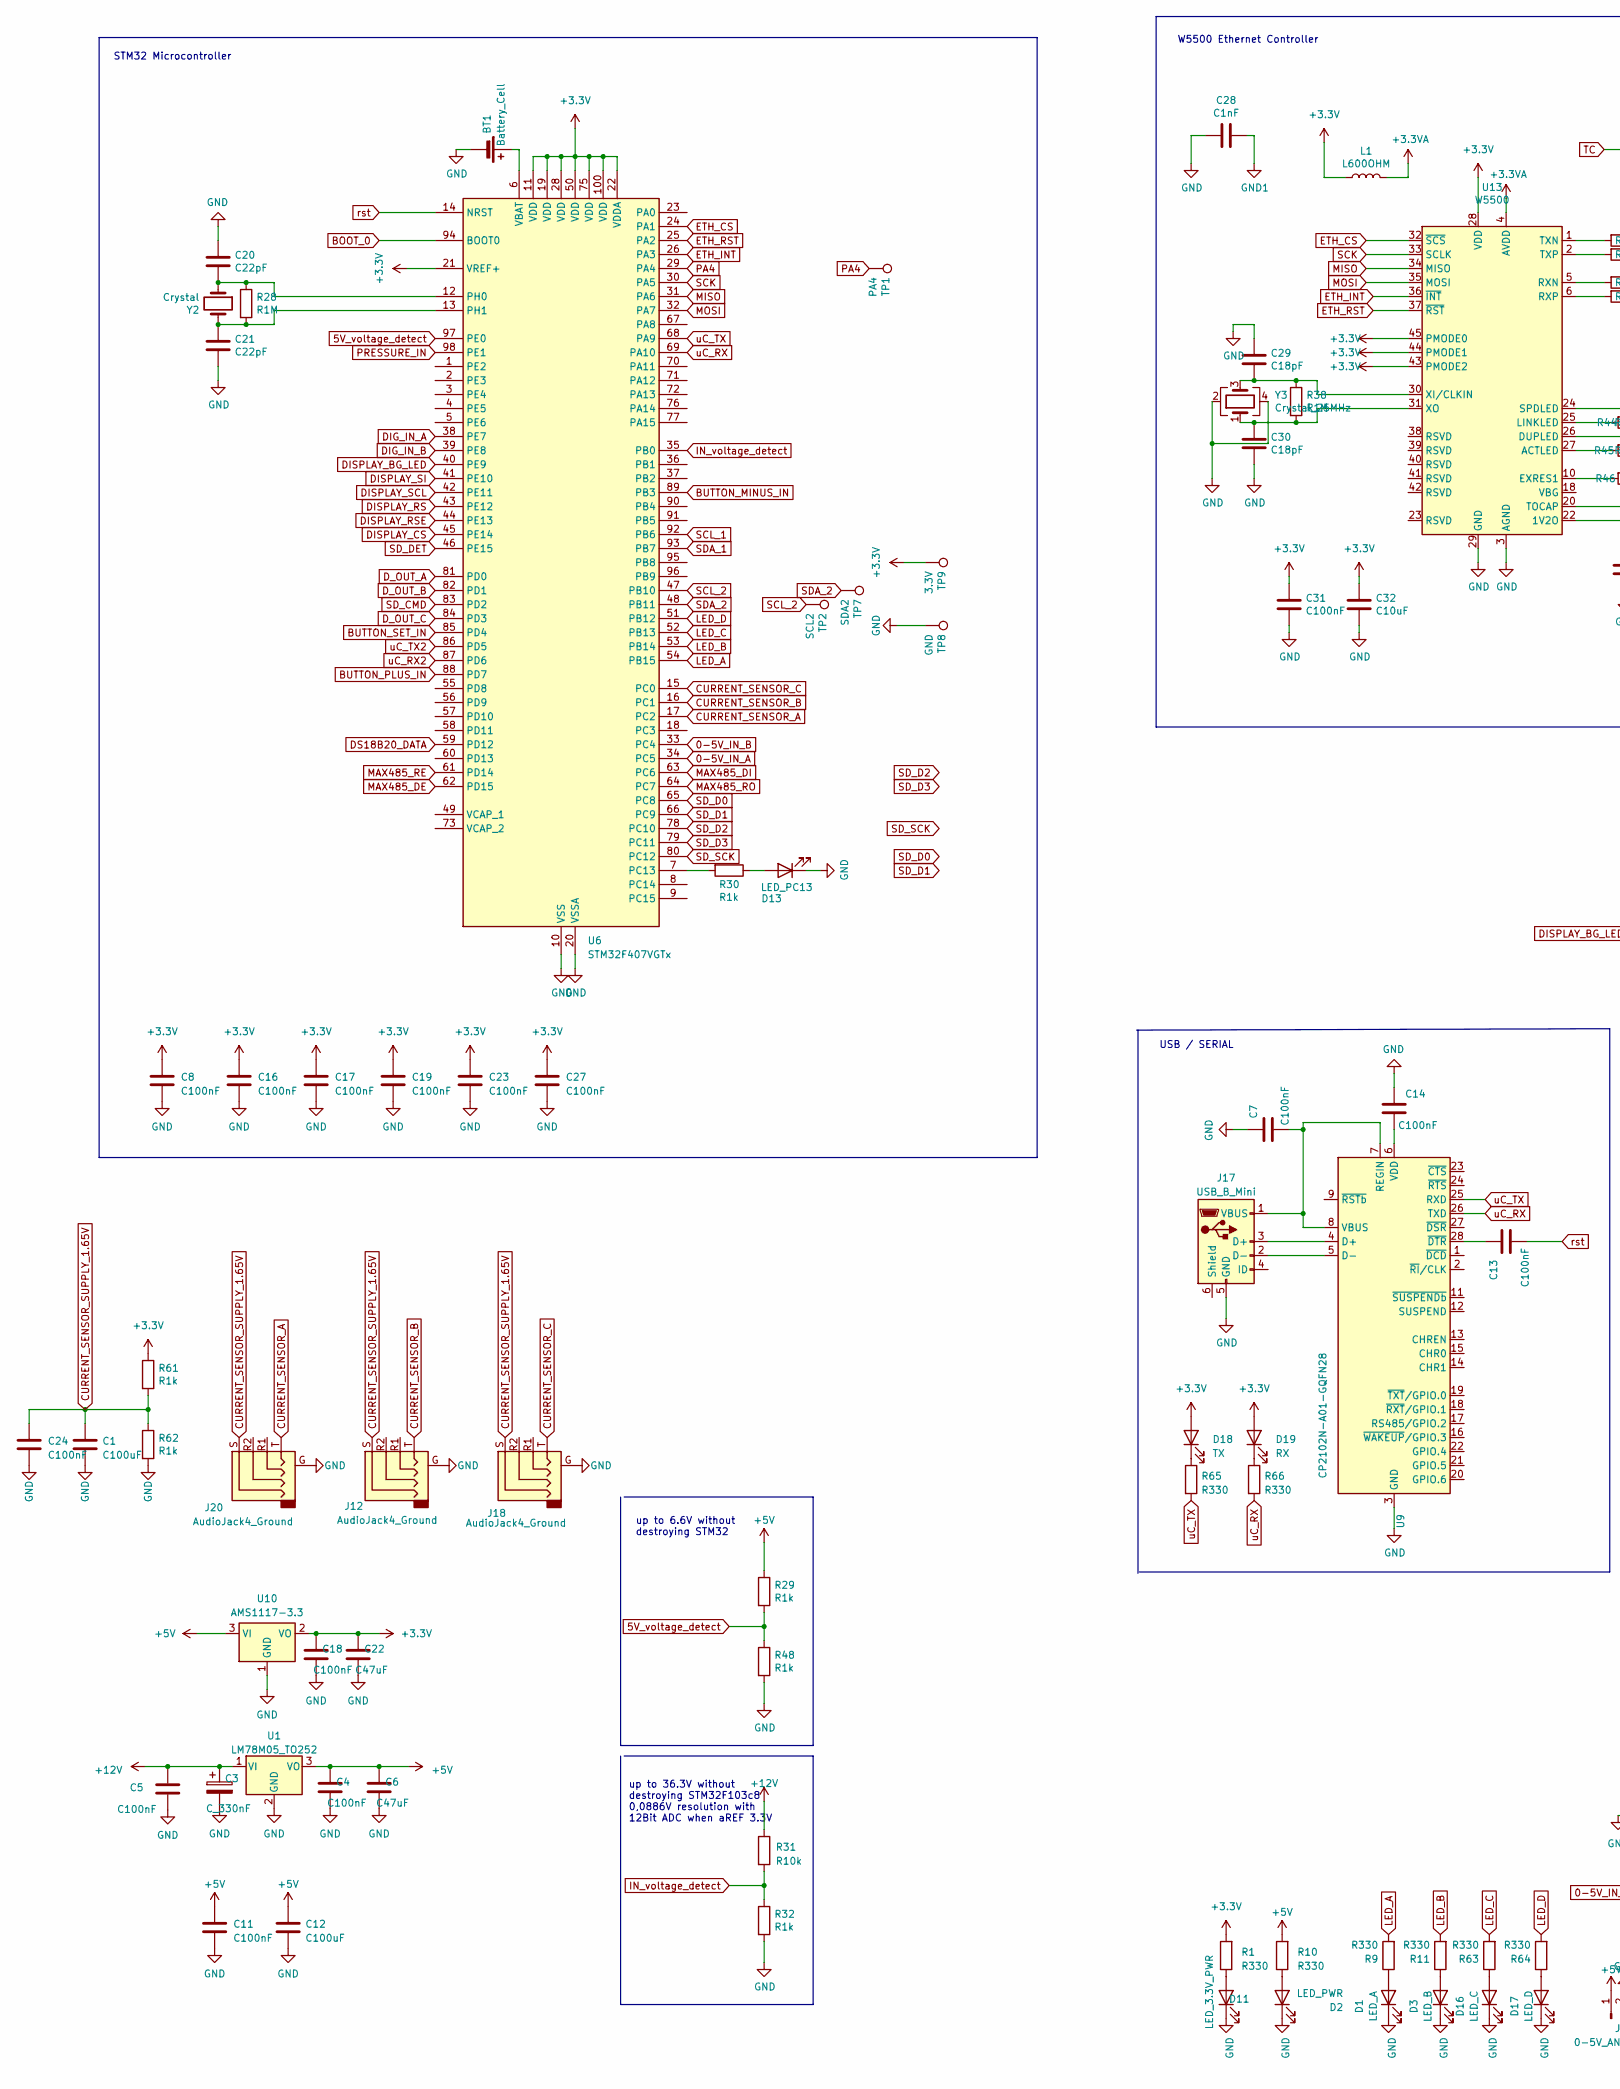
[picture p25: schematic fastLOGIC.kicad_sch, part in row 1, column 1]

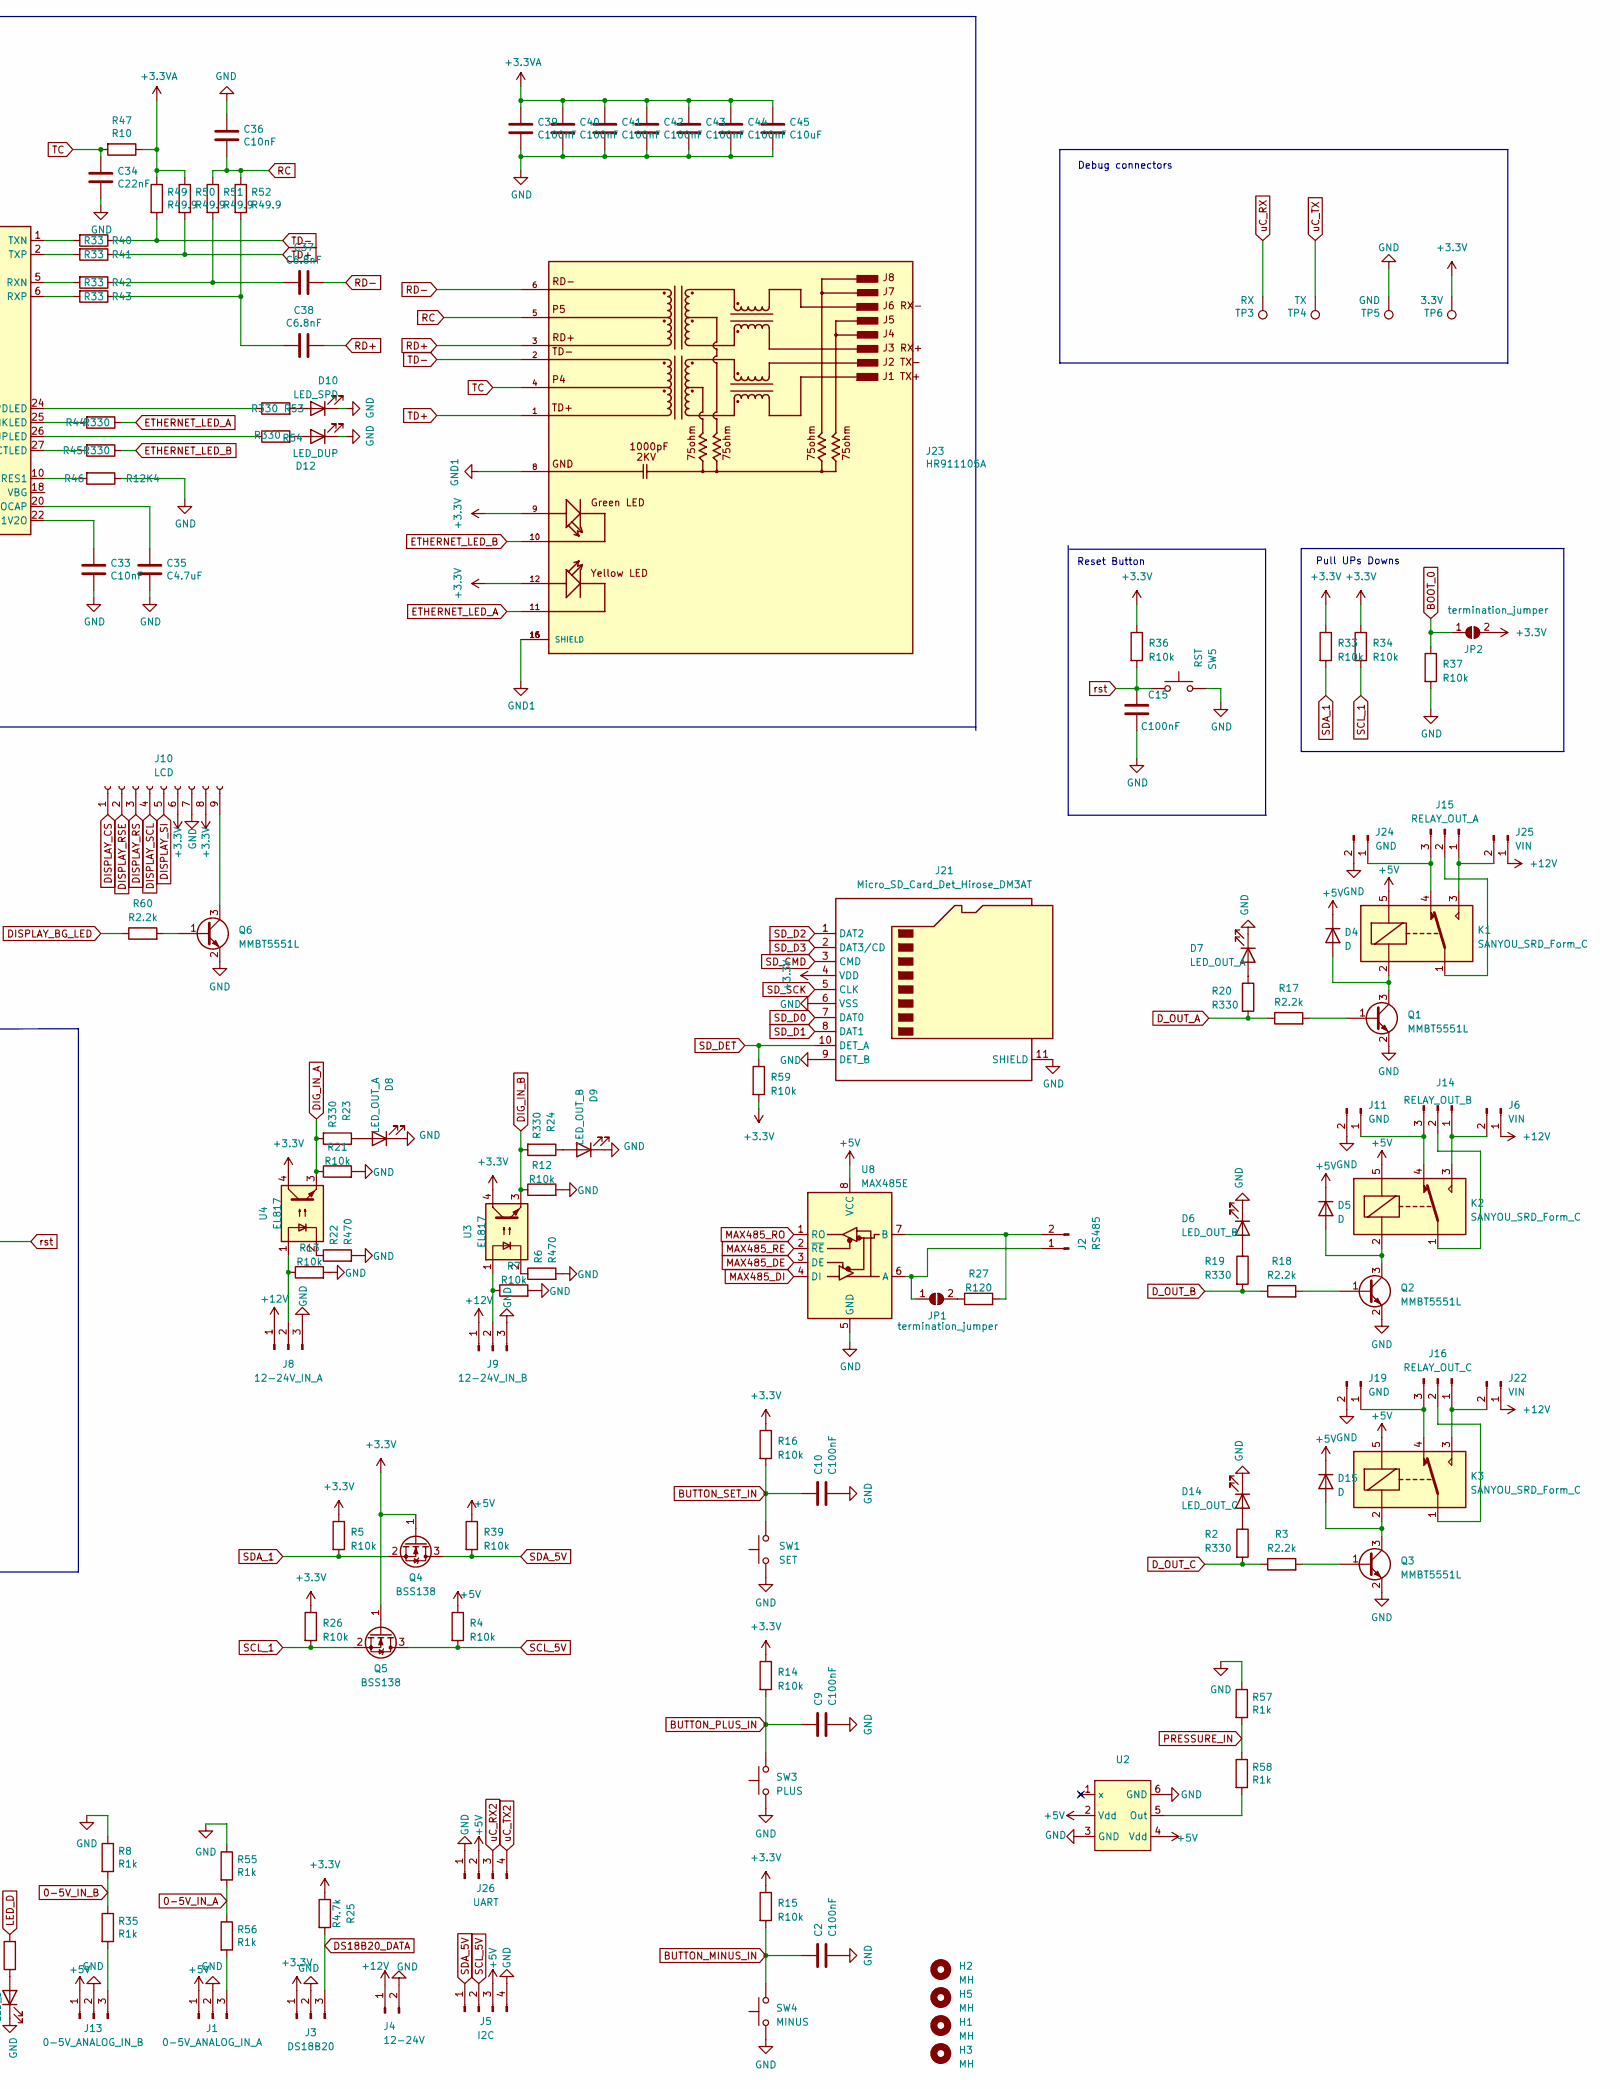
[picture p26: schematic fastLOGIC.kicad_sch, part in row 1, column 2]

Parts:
BT1: Battery_Cell; BatteryHolder_Keystone_1060_1x2032; LCSC C70377
C1, C12: C100uF; C_1206_3216Metric; LCSC C15008
C2, C7, C8, C9, C10, C11, C13, C14, C15, C16, C17, C19, C23, C24, C27, C31: C100nF; C_0603_1608Metric; LCSC C14663
C3: C_330nF; CP_Elec_4x5.4; LCSC C264238
C4, C5, C18: C100nF; C_1206_3216Metric; LCSC C24497
C6, C22: C47uF; C_1206_3216Metric; LCSC C96123
C20, C21: C22pF; C_0402_1005Metric; LCSC C1555
C28: C1nF; C_1206_3216Metric; LCSC C9196
C29, C30: C18pF; C_0402_1005Metric; LCSC C1549
C32, C45: C10uF; C_0805_2012Metric; LCSC C15850
C33: C10nF; C_0402_1005Metric; LCSC C15195
C34: C22nF; C_0603_1608Metric; LCSC C21122
C35: C4.7uF; C_0402_1005Metric; LCSC C23733
C36: C10nF; C_0603_1608Metric; LCSC C57112
C37, C38: C6.8nF; C_0402_1005Metric; LCSC C1542
C39, C40, C41, C42, C43, C44: C100nF; C_0402_1005Metric; LCSC C307331
D1: LED_A; LED_0805_2012Metric; LCSC C2297
D2: LED_PWR; LED_0805_2012Metric; LCSC C84256
D3: LED_B; LED_0805_2012Metric; LCSC C2297
D4, D5, D15: D; D_SMA; LCSC C22452
D6, D9: LED_OUT_B; LED_0805_2012Metric; LCSC C2296
D7, D8: LED_OUT_A; LED_0805_2012Metric; LCSC C2296
D10: LED_SPD; LED_0805_2012Metric; LCSC C2296
D11: LED_3.3V_PWR; LED_0805_2012Metric; LCSC C2296
D12: LED_DUP; LED_0805_2012Metric; LCSC C2296
D13: LED_PC13; LED_0805_2012Metric; LCSC C84256
D14: LED_OUT_C; LED_0805_2012Metric; LCSC C2296
D16: LED_C; LED_0805_2012Metric; LCSC C2297
D17: LED_D; LED_0805_2012Metric; LCSC C2297
D18: TX; LED_0805_2012Metric; LCSC C2297
D19: RX; LED_0805_2012Metric; LCSC C2297
H1, H2, H3, H5: MH; MountingHole_3.2mm_M3_DIN965
J1: 0-5V_ANALOG_IN_A; JST_EH_S3B-EH_1x03_P2.50mm_Horizontal; LCSC C157928
J2: RS485; TerminalBlock_4Ucon_1x02_P3.50mm_Vertical; LCSC C2997509
J3: DS18B20; JST_EH_S3B-EH_1x03_P2.50mm_Horizontal; LCSC C157928
J4: 12-24V; TerminalBlock_4Ucon_1x02_P3.50mm_Vertical; LCSC C2997509
J5: I2C; JST_EH_S4B-EH_1x04_P2.50mm_Horizontal; LCSC C157925
J6, J22, J25: VIN; PinHeader_1x02_P2.54mm_Vertical
J8: 12-24V_IN_A; TerminalBlock_4Ucon_1x03_P3.50mm_Vertical; LCSC C2997510
J9: 12-24V_IN_B; TerminalBlock_4Ucon_1x03_P3.50mm_Vertical; LCSC C2997510
J10: LCD; LCD_GMG12864-06D
J11, J19, J24: GND; PinHeader_1x02_P2.54mm_Vertical
J12, J18, J20: AudioJack4_Ground; Jack_3.5mm_PJ320E_Horizontal
J13: 0-5V_ANALOG_IN_B; JST_EH_S3B-EH_1x03_P2.50mm_Horizontal; LCSC C157928
J14: RELAY_OUT_B; TerminalBlock_4Ucon_1x03_P3.50mm_Vertical; LCSC C2997510
J15: RELAY_OUT_A; TerminalBlock_4Ucon_1x03_P3.50mm_Vertical; LCSC C2997510
J16: RELAY_OUT_C; TerminalBlock_4Ucon_1x03_P3.50mm_Vertical; LCSC C2997510
J17: USB_B_Mini; USB_Mini-B_Tensility_54-00023_Vertical; LCSC C6331167
J21: Micro_SD_Card_Det_Hirose_DM3AT; microSD_HC_Hirose_DM3AT-SF-PEJM5; LCSC C114218
J23: HR911105A; RJ45_Hanrun_HR911105A_Horizontal; PARTREV A; LCSC C12074
J26: UART; JST_EH_B4B-EH-A_1x04_P2.50mm_Vertical; LCSC C157925
JP1, JP2: termination_jumper; PinHeader_1x02_P2.54mm_Vertical
K1, K2, K3: SANYOU_SRD_Form_C; Relay_SPDT_SANYOU_SRD_Series_Form_C; LCSC C35449
L1: L600OHM; L_0805_2012Metric; LCSC C1017
Q1, Q2, Q3, Q6: MMBT5551L; SOT-23; LCSC C2145
Q4, Q5: BSS138; SOT-23; LCSC C112239
R1, R2, R9, R10, R11, R19, R20, R23, R24, R44, R45, R53, R54, R63, R64, R65, R66: R330; R_0603_1608Metric; LCSC C23138
R3, R17, R18, R60: R2.2k; R_0603_1608Metric; LCSC C4190
R4, R5, R7, R12, R13, R14, R15, R16, R21, R26, R31, R33, R34, R36, R37, R39, R59: R10k; R_0603_1608Metric; LCSC C25804
R6, R22: R470; R_0603_1608Metric; LCSC C23179
R8, R29, R30, R32, R35, R48, R55, R56, R57, R58, R61, R62: R1k; R_0603_1608Metric; LCSC C21190
R25: R4.7k; R_0603_1608Metric; LCSC C23162
R27: R120; R_0805_2012Metric; LCSC C17437
R28, R38: R1M; R_0402_1005Metric; LCSC C26083
R40, R41, R42, R43: R33; R_0603_1608Metric; LCSC C23140
R46: R12K4; R_0603_1608Metric; LCSC C22865
R47: R10; R_0603_1608Metric; LCSC C22859
R49, R50, R51, R52: R49.9; R_0603_1608Metric; LCSC C23185
SW1: SET; SW_Push_1P1T_NO_CK_KSC7xxJ; LCSC C318884
SW3: PLUS; SW_Push_1P1T_NO_CK_KSC7xxJ; LCSC C318884
SW4: MINUS; SW_Push_1P1T_NO_CK_KSC7xxJ; LCSC C318884
SW5: RST; SW_Push_1P1T_NO_CK_KSC7xxJ; LCSC C318884
TP1: PA4; TestPoint_Pad_D2.0mm
TP2: SCL2; TestPoint_Pad_D2.0mm
TP3: RX; TestPoint_Pad_D2.0mm
TP4: TX; TestPoint_Pad_D2.0mm
TP5, TP8: GND; TestPoint_Pad_D2.0mm
TP6, TP9: 3.3V; TestPoint_Pad_D2.0mm
TP7: SDA2; TestPoint_Pad_D2.0mm
U1: LM78M05_TO252; TO-252-2; LCSC C58069
U2: XGZP6847A
U3, U4: EL817; DIP-4_W8.89mm_SMDSocket_LongPads; LCSC C106900
U6: STM32F407VGTx; LQFP-100_14x14mm_P0.5mm; LCSC C12345
U8: MAX485E; SOP-8_3.9x4.9mm_P1.27mm; LCSC C481667
U9: CP2102N-A01-GQFN28; QFN-28-1EP_5x5mm_P0.5mm_EP3.35x3.35mm; LCSC C6568
U10: AMS1117-3.3; SOT-223-3_TabPin2; LCSC C6186
U13: W5500; LQFP-48_7x7mm_P0.5mm; LCSC C32843
Y2: Crystal; Crystal_SMD_5032-2Pin_5.0x3.2mm; LCSC C115962
Y3: Crystal_25MHz; Crystal_SMD_3225-4Pin_3.2x2.5mm; LCSC C9006

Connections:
0-5V_IN_A: R55.2, R56.1, U6.34 (PC5)
0-5V_IN_B: R8.2, R35.1, U6.33 (PC4)
5V_voltage_detect: R29.2, R48.1, U6.97 (PE0)
+3.3V: C8.1, C16.1, C17.1, C18.1, C19.1, C22.1, C23.1, C27.1, C31.1, C32.1, D18.2 (A), D19.2 (A), J3.1, J10.6, J10.8, J21.4 (VDD), J23.9, J23.12, JP2.2 (B), L1.1, Q4.1 (G), Q5.1 (G), R1.2, R5.1, R14.1, R15.1, R16.1, R25.1, R26.1, R33.1, R34.1, R36.1, R59.2, R61.1, TP6.1, TP9.1, U3.4, U4.4, U6.11 (VDD), U6.19 (VDD), U6.21 (VREF+), U6.22 (VDDA), U6.28 (VDD), U6.50 (VDD), U6.75 (VDD), U6.100 (VDD), U10.2 (VO), U13.28 (VDD), U13.43 (PMODE2), U13.44 (PMODE1), U13.45 (PMODE0)
+3.3VA: C39.1, C40.1, C41.1, C42.1, C43.1, C44.1, C45.1, L1.2, R47.1, R49.1, R50.1, U13.4 (AVDD), U13.8 (AVDD), U13.11 (AVDD), U13.15 (AVDD), U13.17 (AVDD), U13.21 (AVDD)
+5V: C4.1, C6.1, C11.1, C12.1, D4.1 (K), D5.1 (K), D15.1 (K), J1.1, J5.3, J13.1, J26.2, K1.5, K2.5, K3.5, R4.1, R10.2, R29.1, R39.1, U1.3 (VO), U2.2 (Vdd), U2.4 (Vdd), U8.8 (VCC), U10.3 (VI)
+12V: C3.1, C5.1, J4.1, J6.1, J8.1, J9.1, J22.1, J25.1, R31.1, U1.1 (VI)
BOOT_0: JP2.1 (A), R37.1, U6.94 (BOOT0)
BUTTON_MINUS_IN: C2.1, R15.2, SW4.2, U6.89 (PB3)
BUTTON_PLUS_IN: C9.1, R14.2, SW3.2, U6.88 (PD7)
BUTTON_SET_IN: C10.1, R16.2, SW1.2, U6.85 (PD4)
CURRENT_SENSOR_A: J20.T, U6.17 (PC2)
CURRENT_SENSOR_B: J12.T, U6.16 (PC1)
CURRENT_SENSOR_C: J18.T, U6.15 (PC0)
CURRENT_SENSOR_SUPPLY_1.65V: C1.1, C24.1, J12.S, J18.S, J20.S, R61.2, R62.1
DIG_IN_A: R21.1, R23.2, U4.3, U6.38 (PE7)
DIG_IN_B: R12.1, R24.2, U3.3, U6.39 (PE8)
DISPLAY_BG_LED: R60.1, U6.40 (PE9)
DISPLAY_CS: J10.1, U6.45 (PE14)
DISPLAY_RS: J10.3, U6.43 (PE12)
DISPLAY_RSE: J10.2, U6.44 (PE13)
DISPLAY_SCL: J10.4, U6.42 (PE11)
DISPLAY_SI: J10.5, U6.41 (PE10)
DS18B20_DATA: J3.3, R25.2, U6.59 (PD12)
D_OUT_A: R17.1, R20.2, U6.81 (PD0)
D_OUT_B: R18.1, R19.2, U6.82 (PD1)
D_OUT_C: R2.2, R3.1, U6.84 (PD3)
ETHERNET_LED_A: J23.11, R44.1
ETHERNET_LED_B: J23.10, R45.1
ETH_CS: U6.24 (PA1), U13.32 (~SCS)
ETH_INT: U6.26 (PA3), U13.36 (~INT)
ETH_RST: U6.25 (PA2), U13.37 (~RST)
GND: BT1.2 (-), C1.2, C2.2, C3.2, C4.2, C5.2, C6.2, C7.1, C8.2, C9.2, C10.2, C11.2, C12.2, C14.1, C15.2, C16.2, C17.2, C18.2, C19.2, C20.1, C21.2, C22.2, C23.2, C24.2, C27.2, C28.2, C29.1, C30.2, C31.2, C32.2, C33.2, C34.1, C35.2, C36.1, C39.2, C40.2, C41.2, C42.2, C43.2, C44.2, C45.2, D1.1 (K), D2.1 (K), D3.1 (K), D6.1 (K), D7.1 (K), D8.1 (K), D9.1 (K), D10.1 (K), D11.1 (K), D12.1 (K), D13.1 (K), D14.1 (K), D16.1 (K), D17.1 (K), J1.2, J3.2, J4.2, J5.4, J8.3, J9.3, J10.7, J11.2, J12.G, J13.2, J17.5 (GND), J18.G, J19.2, J20.G, J21.6 (VSS), J21.9 (DET_B), J21.11 (SHIELD), J24.2, J26.1, Q1.2 (E), Q2.2 (E), Q3.2 (E), Q6.2 (E), R6.2, R7.2, R8.1, R12.2, R13.2, R21.2, R22.2, R32.2, R37.2, R46.1, R48.2, R55.1, R57.1, R62.2, SW1.1, SW3.1, SW4.1, SW5.2, TP5.1, TP8.1, U1.2 (GND), U2.3 (GND), U2.6 (GND), U6.10 (VSS), U6.20 (VSSA), U6.27 (VSS), U6.74 (VSS), U6.99 (VSS), U8.5 (GND), U9.3 (GND), U9.29 (GND), U10.1 (GND), U13.3 (AGND), U13.9 (AGND), U13.14 (AGND), U13.16 (AGND), U13.19 (AGND), U13.29 (GND), U13.48 (AGND), Y3.2, Y3.4
GND1: C28.1, J23.8, J23.15 (SHIELD), J23.16 (SHIELD)
IN_voltage_detect: R31.2, R32.1, U6.35 (PB0)
LED_A: R9.2, U6.54 (PB15)
LED_B: R11.2, U6.53 (PB14)
LED_C: R63.2, U6.52 (PB13)
LED_D: R64.2, U6.51 (PB12)
MAX485_DE: U6.62 (PD15), U8.3 (DE)
MAX485_DI: U6.63 (PC6), U8.4 (DI)
MAX485_RE: U6.61 (PD14), U8.2 (~RE)
MAX485_RO: U6.64 (PC7), U8.1 (RO)
MISO: U6.31 (PA6), U13.34 (MISO)
MOSI: U6.32 (PA7), U13.35 (MOSI)
unnamed: BT1.1 (+), U6.6 (VBAT)
unnamed: C37.2, R42.1, R51.2
unnamed: C38.2, R43.1, R52.2
unnamed: D1.2 (A), R9.1
unnamed: D2.2 (A), R10.1
unnamed: D3.2 (A), R11.1
unnamed: D4.2 (A), K1.2, Q1.3 (C)
unnamed: D5.2 (A), K2.2, Q2.3 (C)
unnamed: D6.2 (A), R19.1
unnamed: D7.2 (A), R20.1
unnamed: D8.2 (A), R23.1
unnamed: D9.2 (A), R24.1
unnamed: D10.2 (A), R53.2
unnamed: D11.2 (A), R1.1
unnamed: D12.2 (A), R54.2
unnamed: D13.2 (A), R30.1
unnamed: D14.2 (A), R2.1
unnamed: D15.2 (A), K3.2, Q3.3 (C)
unnamed: D16.2 (A), R63.1
unnamed: D17.2 (A), R64.1
unnamed: D18.1 (K), R65.1
unnamed: D19.1 (K), R66.1
unnamed: J1.3, R56.2
unnamed: J2.1, JP1.1 (A), U8.6 (A)
unnamed: J2.2, R27.2, U8.7 (B)
unnamed: J8.2, R13.1, U4.1
unnamed: J9.2, R7.1, U3.1
unnamed: J10.9, Q6.3 (C)
unnamed: J11.1, J14.3, K2.4
unnamed: J13.3, R35.2
unnamed: J6.2, J14.1, K2.3
unnamed: J14.2, K2.1
unnamed: J15.1, J25.2, K1.3
unnamed: J15.2, K1.1
unnamed: J15.3, J24.1, K1.4
unnamed: J16.1, J22.2, K3.3
unnamed: J16.2, K3.1
unnamed: J16.3, J19.1, K3.4
unnamed: J17.3 (D+), U9.4 (D+)
unnamed: J17.2 (D-), U9.5 (D-)
unnamed: C7.2, J17.1 (VBUS), U9.7 (REGIN), U9.8 (VBUS)
unnamed: JP1.2 (B), R27.1
unnamed: Q1.1 (B), R17.2
unnamed: Q2.1 (B), R18.2
unnamed: Q3.1 (B), R3.2
unnamed: Q6.1 (B), R60.2
unnamed: R6.1, U3.2
unnamed: R22.1, U4.2
unnamed: R58.2, U2.5 (Out)
unnamed: R30.2, U6.7 (PC13)
unnamed: C20.2, R28.1, U6.12 (PH0), Y2.1
unnamed: C21.1, R28.2, U6.13 (PH1), Y2.2
unnamed: C14.2, U9.6 (VDD)
unnamed: C13.1, U9.28 (~DTR)
unnamed: C33.1, U13.22 (1V2O)
unnamed: R45.2, U13.27 (ACTLED)
unnamed: R54.1, U13.26 (DUPLED)
unnamed: R46.2, U13.10 (EXRES1)
unnamed: R44.2, U13.25 (LINKLED)
unnamed: R42.2, U13.5 (RXN)
unnamed: R43.2, U13.6 (RXP)
unnamed: R53.1, U13.24 (SPDLED)
unnamed: C35.1, U13.20 (TOCAP)
unnamed: R40.2, U13.1 (TXN)
unnamed: R41.2, U13.2 (TXP)
unnamed: C29.2, R38.1, U13.30 (XI/CLKIN), Y3.3
unnamed: C30.1, R38.2, U13.31 (XO), Y3.1
PA4: TP1.1, U6.29 (PA4)
PRESSURE_IN: R57.2, R58.1, U6.98 (PE1)
RC: C36.2, J23.5, R51.1, R52.1
RD+: C38.1, J23.3
RD-: C37.1, J23.6
SCK: U6.30 (PA5), U13.33 (SCLK)
SCL_1: Q5.2 (S), R26.2, R34.2, U6.92 (PB6)
SCL_2: TP2.1, U6.47 (PB10)
SCL_5V: J5.2, Q5.3 (D), R4.2
SDA_1: Q4.2 (S), R5.2, R33.2, U6.93 (PB7)
SDA_2: TP7.1, U6.48 (PB11)
SDA_5V: J5.1, Q4.3 (D), R39.2
SD_CMD: J21.3 (CMD), U6.83 (PD2)
SD_D0: J21.7 (DAT0), U6.65 (PC8)
SD_D1: J21.8 (DAT1), U6.66 (PC9)
SD_D2: J21.1 (DAT2), U6.78 (PC10)
SD_D3: J21.2 (DAT3/CD), U6.79 (PC11)
SD_DET: J21.10 (DET_A), R59.1, U6.46 (PE15)
SD_SCK: J21.5 (CLK), U6.80 (PC12)
TC: C34.2, J23.4, R47.2
TD+: J23.1, R41.1, R50.2
TD-: J23.2, R40.1, R49.2
rst: C13.2, C15.1, R36.2, SW5.1, U6.14 (NRST)
uC_RX: R66.2, TP3.1, U6.69 (PA10), U9.26 (TXD)
uC_RX2: J26.3, U6.87 (PD6)
uC_TX: R65.2, TP4.1, U6.68 (PA9), U9.25 (RXD)
uC_TX2: J26.4, U6.86 (PD5)

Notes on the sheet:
up to 6.6V without destroying STM32
Pull UPs Downs
USB / SERIAL
Debug connectors
up to 36.3V without destroying STM32F103c8 0,0886V resolution with 12Bit ADC when aREF 3.3V
Reset Button
STM32 Microcontroller
W5500 Ethernet Controller

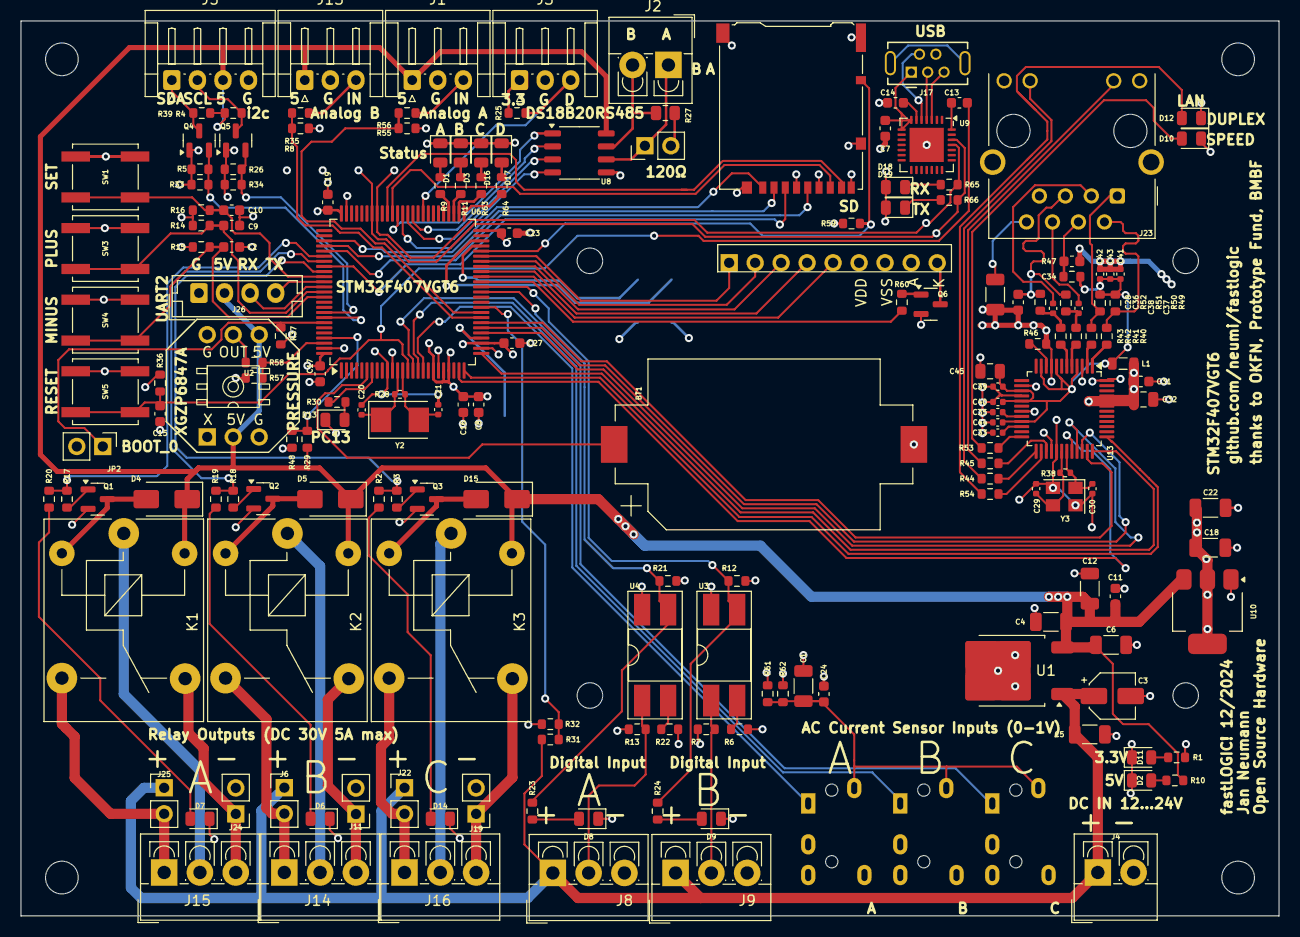
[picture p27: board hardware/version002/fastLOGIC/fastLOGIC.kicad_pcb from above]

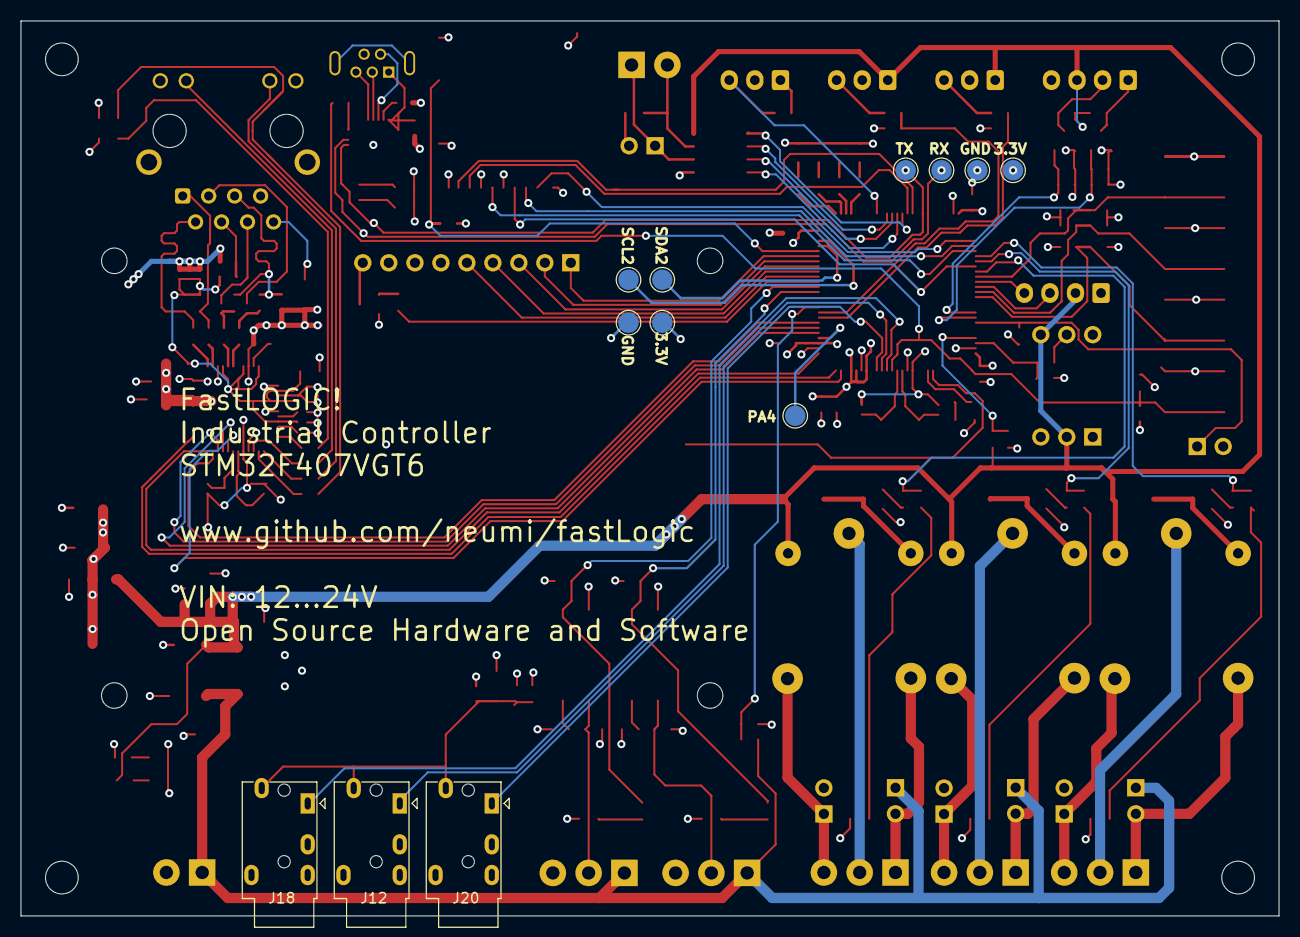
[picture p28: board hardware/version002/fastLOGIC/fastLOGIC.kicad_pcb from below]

Board: 4 copper layers, 123.0 x 87.5 mm, 194 parts (12 on the bottom side), 139 nets.

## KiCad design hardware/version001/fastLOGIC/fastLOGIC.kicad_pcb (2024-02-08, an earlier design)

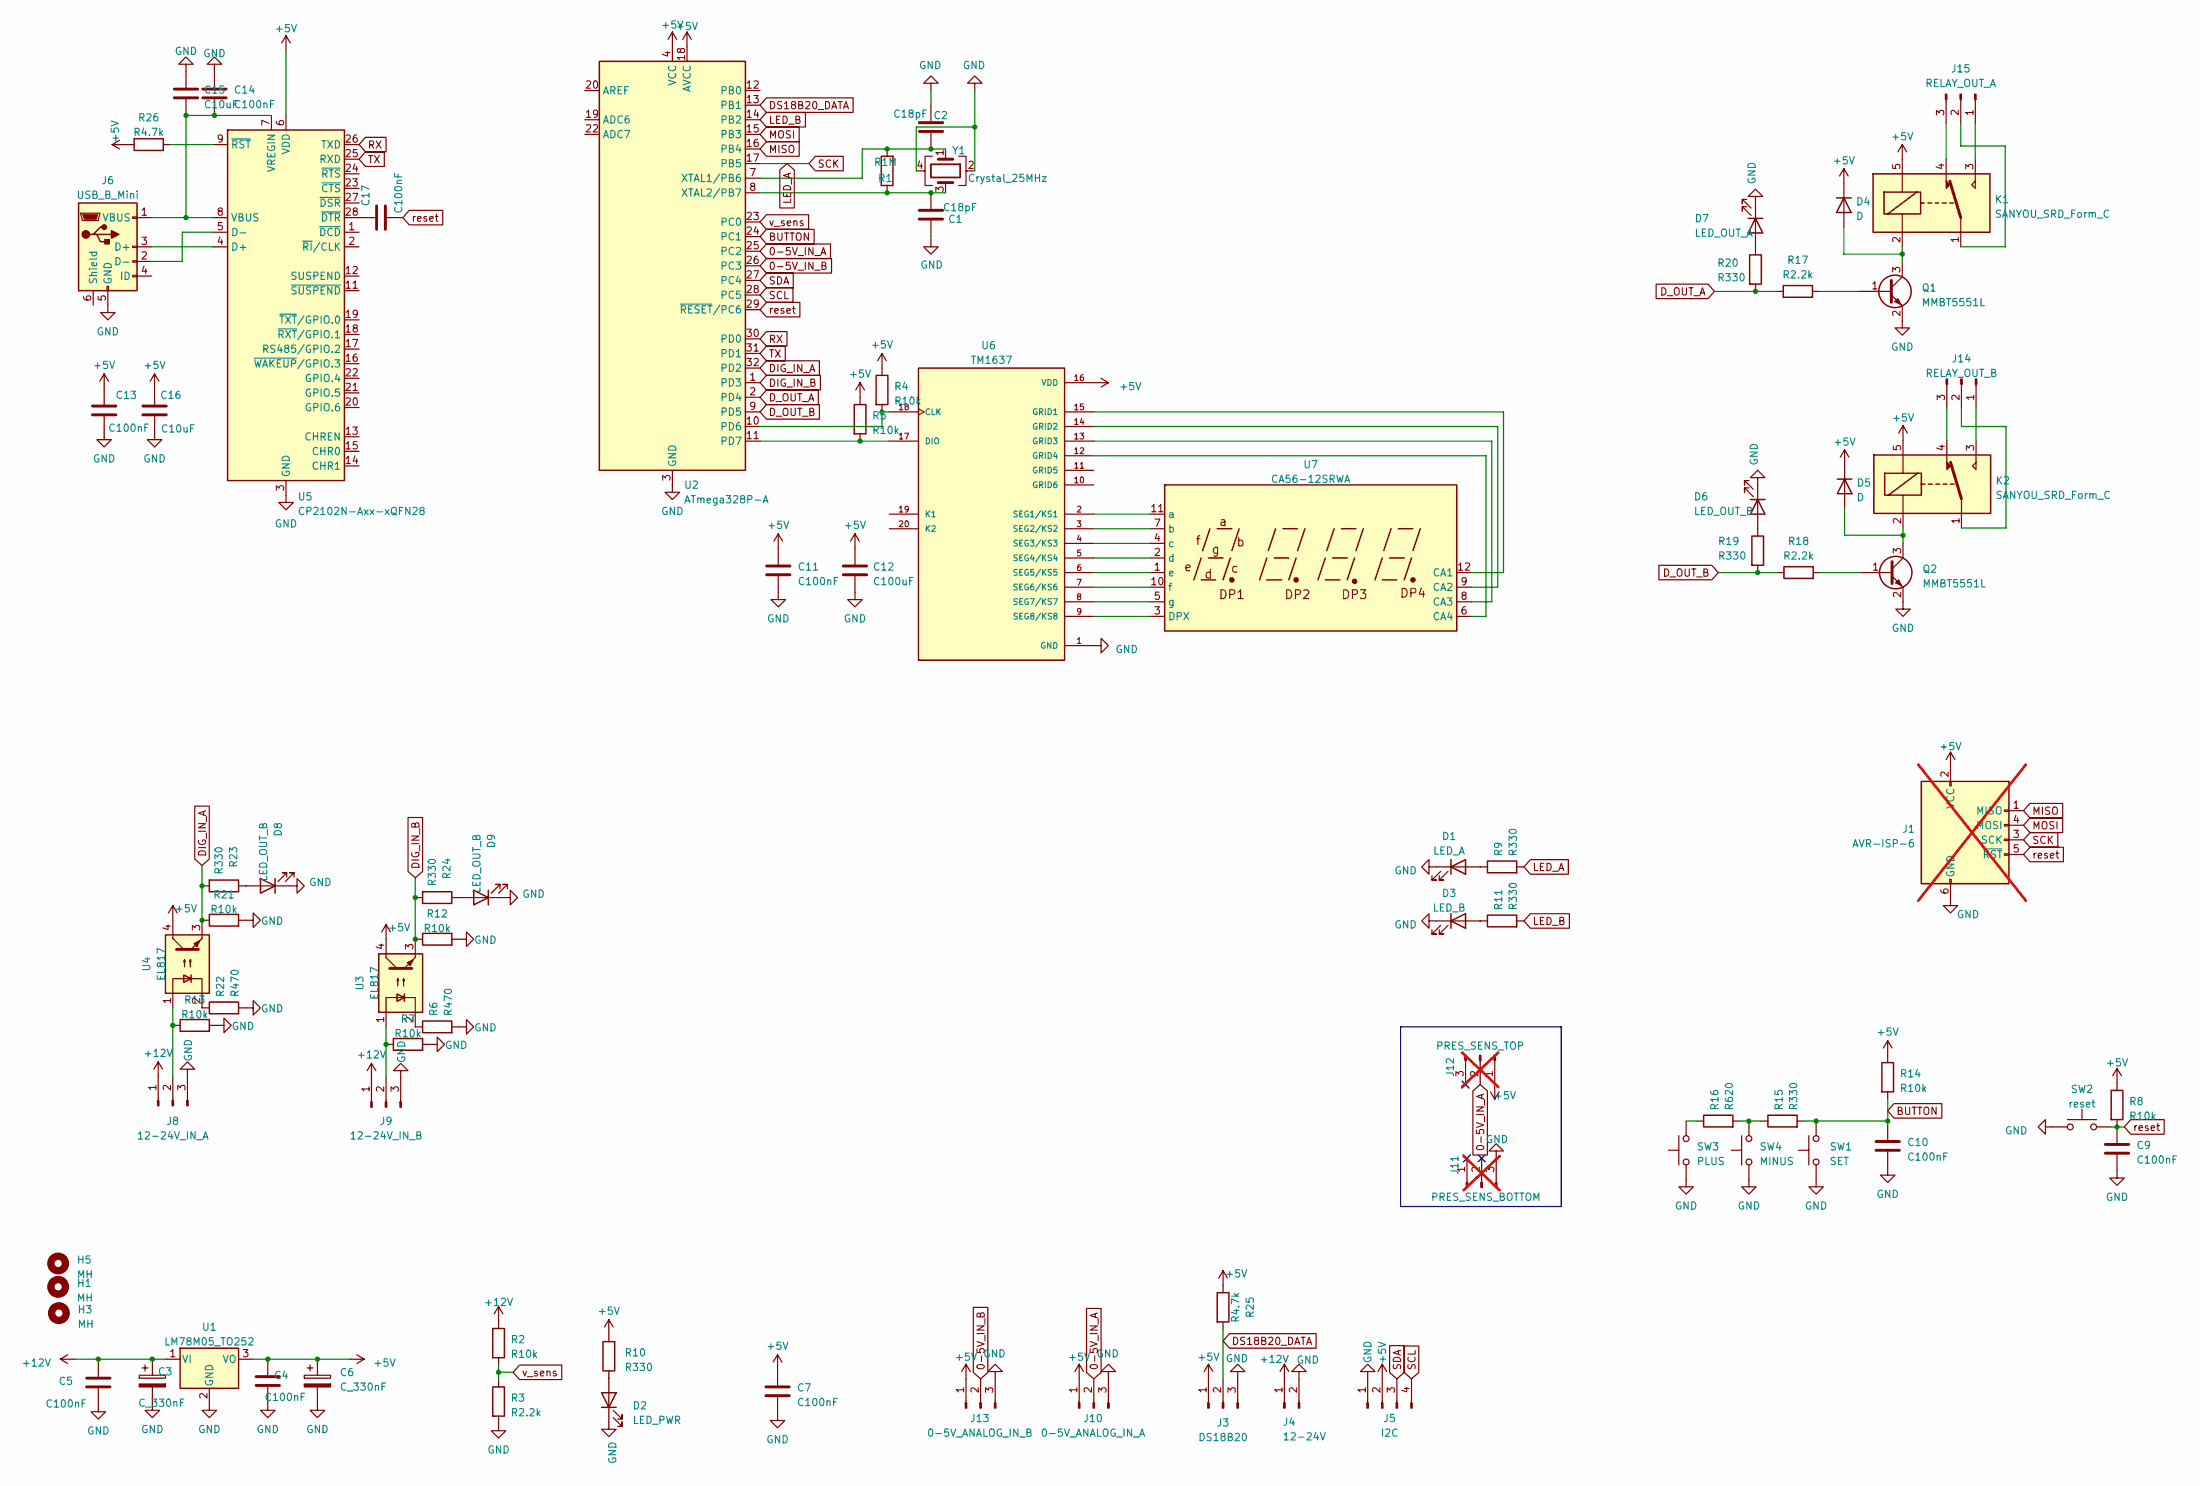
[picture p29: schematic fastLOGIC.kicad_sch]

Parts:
C1, C2: C18pF; C_0402_1005Metric; LCSC C1549
C3, C6: C_330nF; CP_Elec_4x5.4; LCSC C264238
C4, C5: C100nF; C_1206_3216Metric; LCSC C24497
C7, C9, C10, C11, C13, C14, C17: C100nF; C_0603_1608Metric; LCSC C14663
C12: C100uF; C_1206_3216Metric; LCSC C15008
C15, C16: C10uF; C_0805_2012Metric; LCSC C15850
D1: LED_A; LED_0805_2012Metric; LCSC C2296
D2: LED_PWR; LED_0805_2012Metric; LCSC C84256
D3: LED_B; LED_0805_2012Metric; LCSC C2296
D4, D5: D; D_SMA; LCSC C22452
D6, D8, D9: LED_OUT_B; LED_0805_2012Metric; LCSC C2296
D7: LED_OUT_A; LED_0805_2012Metric; LCSC C2296
H1, H3, H5: MH; MountingHole_3.2mm_M3_DIN965
J1: AVR-ISP-6; IDC-Header_2x03_P2.54mm_Vertical; not fitted
J3: DS18B20; JST_EH_S3B-EH_1x03_P2.50mm_Horizontal; LCSC C157928
J4: 12-24V; TerminalBlock_4Ucon_1x02_P3.50mm_Vertical; LCSC C2997509
J5: I2C; JST_EH_S4B-EH_1x04_P2.50mm_Horizontal; LCSC C157925
J6: USB_B_Mini; USB_Mini-B_Tensility_54-00023_Vertical; LCSC C6331167
J8: 12-24V_IN_A; TerminalBlock_4Ucon_1x03_P3.50mm_Vertical; LCSC C2997510
J9: 12-24V_IN_B; TerminalBlock_4Ucon_1x03_P3.50mm_Vertical; LCSC C2997510
J10: 0-5V_ANALOG_IN_A; JST_EH_S3B-EH_1x03_P2.50mm_Horizontal; LCSC C157928
J11: PRES_SENS_BOTTOM; PinHeader_1x03_P2.54mm_Vertical; not fitted
J12: PRES_SENS_TOP; PinHeader_1x03_P2.54mm_Vertical; not fitted
J13: 0-5V_ANALOG_IN_B; JST_EH_S3B-EH_1x03_P2.50mm_Horizontal; LCSC C157928
J14: RELAY_OUT_B; TerminalBlock_4Ucon_1x03_P3.50mm_Vertical; LCSC C2997510
J15: RELAY_OUT_A; TerminalBlock_4Ucon_1x03_P3.50mm_Vertical; LCSC C2997510
K1, K2: SANYOU_SRD_Form_C; Relay_SPDT_SANYOU_SRD_Series_Form_C; LCSC C35449
Q1, Q2: MMBT5551L; SOT-23; LCSC C2145
R1: R1M; R_0603_1608Metric; LCSC C22935
R2, R4, R5, R7, R8, R12, R13, R14, R21: R10k; R_0603_1608Metric; LCSC C25804
R3, R17, R18: R2.2k; R_0603_1608Metric; LCSC C4190
R6, R22: R470; R_0603_1608Metric; LCSC C23179
R9, R10, R11, R15, R19, R20, R23, R24: R330; R_0603_1608Metric; LCSC C23138
R16: R620; R_0603_1608Metric; LCSC C4260
R25, R26: R4.7k; R_0603_1608Metric; LCSC C23162
SW1: SET; SW_Push_1P1T_NO_CK_KSC7xxJ; LCSC C318884
SW2: reset; SW_Push_1P1T_NO_CK_KSC7xxJ; LCSC C318884
SW3: PLUS; SW_Push_1P1T_NO_CK_KSC7xxJ; LCSC C318884
SW4: MINUS; SW_Push_1P1T_NO_CK_KSC7xxJ; LCSC C318884
U1: LM78M05_TO252; TO-252-2; LCSC C58069
U2: ATmega328P-A; TQFP-32_7x7mm_P0.8mm
U3, U4: EL817; DIP-4_W8.89mm_SMDSocket_LongPads; LCSC C106900
U5: CP2102N-Axx-xQFN28; QFN-28-1EP_5x5mm_P0.5mm_EP3.35x3.35mm; LCSC C6568
U6: TM1637; SOP-20_7.5x12.8mm_P1.27mm; PARTREV v2.5; LCSC C2962580
U7: CA56-12SRWA; LCSC C38183
Y1: Crystal_25MHz; Crystal_SMD_3225-4Pin_3.2x2.5mm; LCSC C13738

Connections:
0-5V_IN_A: J10.2, J12.2, U2.25 (PC2)
0-5V_IN_B: J13.2, U2.26 (PC3)
+5V: C4.1, C6.1, C7.1, C11.1, C12.1, C13.1, C16.1, D4.1 (K), D5.1 (K), J1.2 (VCC), J3.1, J5.2, J10.1, J12.1, J13.1, K1.5, K2.5, R4.1, R5.1, R8.1, R10.2, R14.1, R25.1, R26.1, U1.3 (VO), U2.4 (VCC), U2.6 (VCC), U2.18 (AVCC), U3.4, U4.4, U5.6 (VDD), U6.16 (VDD)
+12V: C3.1, C5.1, J4.1, J8.1, J9.1, R2.1, U1.1 (VI)
BUTTON: C10.1, R14.2, R15.2, SW1.2, U2.24 (PC1)
DIG_IN_A: R21.1, R23.2, U2.32 (PD2), U4.3
DIG_IN_B: R12.1, R24.2, U2.1 (PD3), U3.3
DS18B20_DATA: J3.2, R25.2, U2.13 (PB1)
D_OUT_A: R17.1, R20.2, U2.2 (PD4)
D_OUT_B: R18.1, R19.2, U2.9 (PD5)
GND: C1.1, C2.2, C3.2, C4.2, C5.2, C6.2, C7.2, C9.2, C10.2, C11.2, C12.2, C13.2, C14.1, C15.1, C16.2, D1.1 (K), D2.1 (K), D3.1 (K), D6.1 (K), D7.1 (K), D8.1 (K), D9.1 (K), J1.6 (GND), J3.3, J4.2, J5.1, J6.5 (GND), J8.3, J9.3, J10.3, J11.3, J13.3, Q1.2 (E), Q2.2 (E), R3.2, R6.2, R7.2, R12.2, R13.2, R21.2, R22.2, SW1.1, SW2.1, SW3.1, SW4.1, U1.2 (GND), U2.3 (GND), U2.5 (GND), U2.21 (GND), U5.3 (GND), U5.29 (GND), U6.1 (GND), Y1.2, Y1.4
LED_A: J1.3 (SCK), R9.2, U2.17 (PB5)
LED_B: R11.2, U2.14 (PB2)
MISO: J1.1 (MISO), U2.16 (PB4)
MOSI: J1.4 (MOSI), U2.15 (PB3)
unnamed: D1.2 (A), R9.1
unnamed: D2.2 (A), R10.1
unnamed: D3.2 (A), R11.1
unnamed: D4.2 (A), K1.2, Q1.3 (C)
unnamed: D5.2 (A), K2.2, Q2.3 (C)
unnamed: D6.2 (A), R19.1
unnamed: D7.2 (A), R20.1
unnamed: D8.2 (A), R23.1
unnamed: D9.2 (A), R24.1
unnamed: J6.3 (D+), U5.4 (D+)
unnamed: J6.2 (D-), U5.5 (D-)
unnamed: C14.2, C15.2, J6.1 (VBUS), U5.7 (VREGIN), U5.8 (VBUS)
unnamed: J8.2, R13.1, U4.1
unnamed: J9.2, R7.1, U3.1
unnamed: J14.1, K2.3
unnamed: J14.2, K2.1
unnamed: J14.3, K2.4
unnamed: J15.1, K1.3
unnamed: J15.2, K1.1
unnamed: J15.3, K1.4
unnamed: Q1.1 (B), R17.2
unnamed: Q2.1 (B), R18.2
unnamed: R6.1, U3.2
unnamed: R15.1, R16.2, SW4.2
unnamed: R16.1, SW3.2
unnamed: R22.1, U4.2
unnamed: R4.2, U2.10 (PD6), U6.18 (CLK)
unnamed: R5.2, U2.11 (PD7), U6.17 (DIO)
unnamed: C2.1, R1.2, U2.7 (XTAL1/PB6), Y1.1
unnamed: C1.2, R1.1, U2.8 (XTAL2/PB7), Y1.3
unnamed: C17.1, U5.28 (~DTR)
unnamed: R26.2, U5.9 (~RST)
unnamed: U6.15 (GRID1), U7.12 (CA1)
unnamed: U6.14 (GRID2), U7.9 (CA2)
unnamed: U6.13 (GRID3), U7.8 (CA3)
unnamed: U6.12 (GRID4), U7.6 (CA4)
unnamed: U6.2 (SEG1/KS1), U7.11 (a)
unnamed: U6.3 (SEG2/KS2), U7.7 (b)
unnamed: U6.4 (SEG3/KS3), U7.4 (c)
unnamed: U6.5 (SEG4/KS4), U7.2 (d)
unnamed: U6.6 (SEG5/KS5), U7.1 (e)
unnamed: U6.7 (SEG6/KS6), U7.10 (f)
unnamed: U6.8 (SEG7/KS7), U7.5 (g)
unnamed: U6.9 (SEG8/KS8), U7.3 (DPX)
RX: U2.30 (PD0), U5.26 (TXD)
SCL: J5.4, U2.28 (PC5)
SDA: J5.3, U2.27 (PC4)
TX: U2.31 (PD1), U5.25 (RXD)
reset: C9.1, C17.2, J1.5 (~RST), R8.2, SW2.2, U2.29 (~RESET/PC6)
v_sens: R2.2, R3.1, U2.23 (PC0)

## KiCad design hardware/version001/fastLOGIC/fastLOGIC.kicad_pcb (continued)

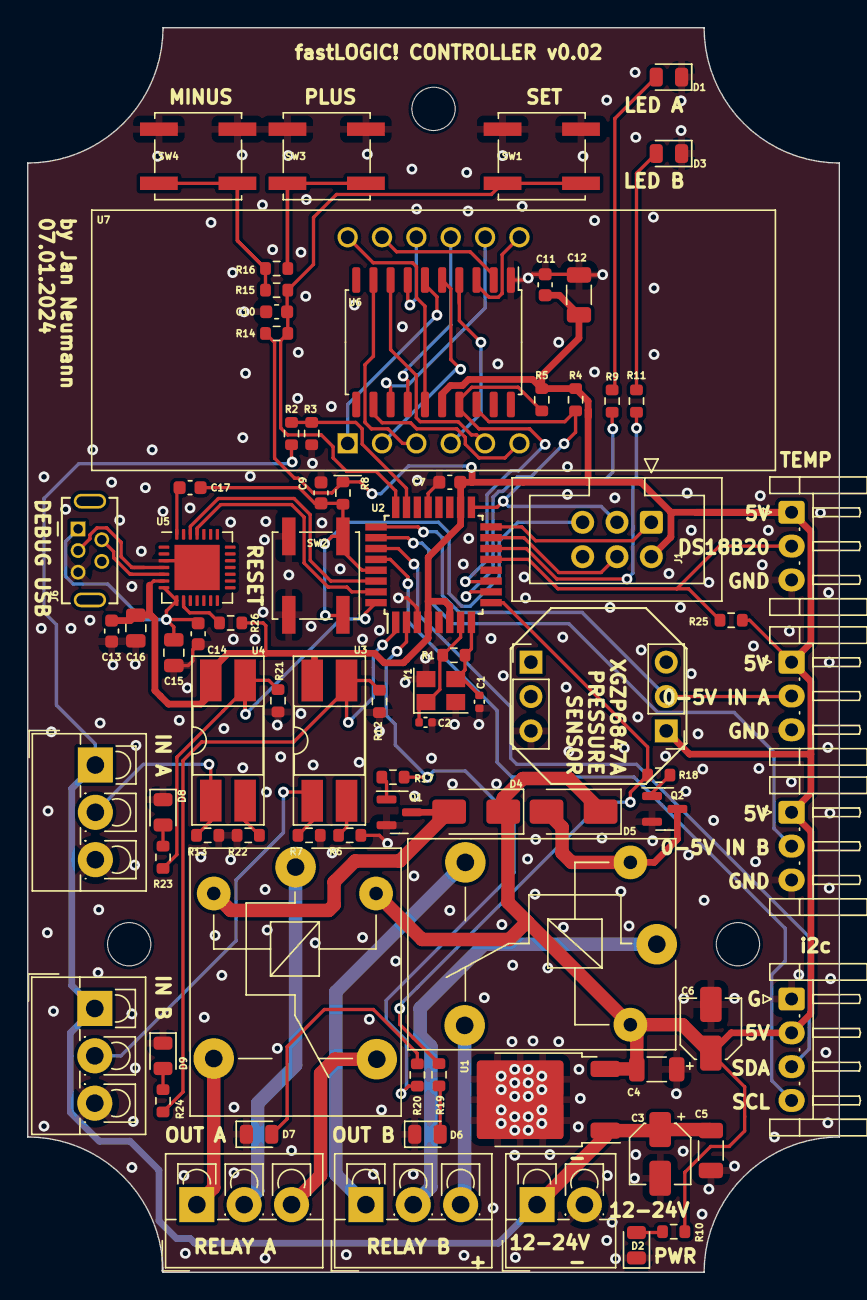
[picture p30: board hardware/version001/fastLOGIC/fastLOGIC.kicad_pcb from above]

Board: 2 copper layers, 60.0 x 92.0 mm, 83 parts (0 on the bottom side), 65 nets.

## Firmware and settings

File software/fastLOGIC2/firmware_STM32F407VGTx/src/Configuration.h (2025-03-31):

#pragma once

const String version = "0.21"; // software version

#define STATIC_IP 0 // when set 1, DHCP is enabled, when 0, statis IP is used

#define DEBUG_MODE 1 // when set 1, debugging output is enabled

#define BAUD_SPEED 9600 // debug and message baud speed

#define SYS_VOL 3.3 // system voltage in volts

#define BUFFER_SIZE 256 // communication buffer size

#define LOCAL_PORT 8888 // local UDP port

#define STANDARD_REMOTE_SENSOR_PORT 5000 // remote machines receiving UDP port

#define DEFAULT_DISPLAY_REFRESH_TIME 100 // milliseconds until new data is shown
#define DEFAULT_FEEDBACK_TIME 100 // milliseconds until hearbeat


// scheduler modes
#define standby 0 // waiting for instructions
#define running 1 // running drive loop

// connection modes
#define CONNECTION_STAT "STAT"
#define CONNECTION_DHCP "DHCP"
#define CONNECTION_USB "USB "
 

// I/O
#define LED_PIN PC13

#define LCD_BG_LED_PIN PE9
#define LCD_SI PE10
#define LCD_SCL PE11    
#define LCD_RS PE12
#define LCD_RSE PE13
#define LCD_CS PE14

#define SD_DET PE15
#define SD_CMD PD2
#define SD_D0 PC8
#define SD_D1 PC9
#define SD_D2 PC10
#define SD_D3 PC11
#define SD_CLK PC12

#define MAX485_DI PC6
#define MAX485_RO PC7
#define MAX485_RE PD14
#define MAX485_DE PD15

#define ETHERNET_INT PA3
#define ETHERNET_RST PA2
#define ETHERNET_CS PA1
#define ETHERNET_MISO PA6
#define ETHERNET_MOSI PA7
#define ETHERNET_SCK PA5

#define DS18B20_PIN PD12

#define TX1 PA9
#define RX1 PA10
#define TX2 PD5
#define RX2 PD6

#define SCL1 PB6
#define SDA1 PB7
#define SCL2 PB10
#define SDA2 PB11

#define LEDA PB15
#define LEDB PB14
#define LEDC PB13
#define LEDD PB12

#define DIGITAL_IN_A PE7
#define DIGITAL_IN_B PE8

#define RELAY_OUT_A PD0
#define RELAY_OUT_B PD1
#define RELAY_OUT_C PD3

#define BUTTON_SET_IN PD4
#define BUTTON_PLUS_IN PD7
#define BUTTON_MINUS_IN PB3

#define VOLT_DETECT_PIN_5V PE0 // false pinmap NOT SUITABLE FOR ADC VOLTAGE MEASUREMENT
#define VOLT_DETECT_PIN_VIN PB0

#define ANALOG_IN_A PC5
#define ANALOG_IN_B PC4

#define PRESSURE_SENSOR_PIN PE1 // false pinmap NOT SUITABLE FOR ADC PRESSURE MEASUREMENT

#define CURRENT_SENSE_PIN_A PC2
#define CURRENT_SENSE_PIN_B PC1
#define CURRENT_SENSE_PIN_C PC0

#define UC_TX PA9
#define UC_RX PA10

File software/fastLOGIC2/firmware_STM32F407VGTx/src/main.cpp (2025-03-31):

#include <Arduino.h>
#include <U8x8lib.h>
#include <STM32RTC.h>
#include "Configuration.h"
#include <OneWire.h>
#include <DallasTemperature.h>
#include "IOManager.h"


// Define your hardware pins for the display
#define LCD_BG_LED_PIN PE9
#define LCD_SI PE10
#define LCD_SCL PE11    
#define LCD_RS PE12
#define LCD_RSE PE13
#define LCD_CS PE14

// Initialize display
U8X8_ST7565_LX12864_4W_SW_SPI u8x8(
  /* clock=*/ LCD_SCL, 
  /* data=*/ LCD_SI, 
  /* cs=*/ LCD_CS, 
  /* dc=*/ LCD_RS, 
  /* reset=*/ LCD_RSE
);

// Initialize RTC
STM32RTC& rtc = STM32RTC::getInstance();
#define ONE_WIRE_BUS  // Adjust this to your pin

// Setup a oneWire instance to communicate with any OneWire devices
OneWire oneWire(DS18B20_PIN);

// Pass the oneWire reference to DallasTemperature library
DallasTemperature DS18b20Sensors(&oneWire);

// Define the CP2102 serial port
HardwareSerial Serial1(UC_RX, UC_TX);

IOManager ioManager;  // Correct: Declare an instance of IOManager


void setup() {
  // Setup LCD backlight
  pinMode(LCD_BG_LED_PIN, OUTPUT);
  digitalWrite(LCD_BG_LED_PIN, HIGH);
  Serial1.begin(115200);

  // Initialize the display
  u8x8.begin();
  u8x8.setPowerSave(0);
  u8x8.setFont(u8x8_font_chroma48medium8_r);
  u8x8.setFont(u8x8_font_amstrad_cpc_extended_f);
  u8x8.setContrast(63);

  // Display startup message
  u8x8.clear();
  u8x8.println("DS18b20 Example");
  delay(200);

  
  DS18b20Sensors.begin();

}

void loop() {

  DS18b20Sensors.requestTemperatures();

  // Fetch the temperature in Celsius
  float temperatureC = DS18b20Sensors.getTempCByIndex(0);

  // Print the temperature to Serial
  if (temperatureC != DEVICE_DISCONNECTED_C) {
    Serial1.print("Temperature: ");
    Serial1.print(temperatureC);
    Serial1.println(" °C");

    u8x8.clear();
    u8x8.print(temperatureC);
    u8x8.println(" °C");

    u8x8.print("VCC: ");
    u8x8.println(ioManager.getBoardVoltage());
    u8x8.print("VIN: ");
    u8x8.println(ioManager.getInputVoltage());

    u8x8.print("V anlg. A: ");
    u8x8.print(ioManager.readAnalogInA());

    // refresh only the temperature display area
    
  } else {
    Serial1.println("Error: Could not read temperature");
  }


  delay(500); // Update every second

  
}

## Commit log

2023-12-06 initial hardware and images
    [PCB Terminal Block 2 DEG381-3.5.step, PCB Terminal Block 3 DEG381-3.5.step, TM1637.step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]
2023-12-06 layout changes, mini usb connector, case with lid 3d, minor stuff
    [Mini-B USB Vertical.stp, bom.csv, designators.csv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]
2023-12-06 added assembly image
2023-12-06 removed old production files
    [bom.csv, designators.csv, positions.csv]
2023-12-06 hardware chnages minor
    [fastLOGIC.kicad_pcb, fastLOGIC.kicad_sch]
2023-12-06 added production folder of JLC order
    [bom.csv, designators.csv, positions.csv]
2023-12-06 removed old production
    [bom.csv, designators.csv, positions.csv]
2023-12-06 latest pcb
    [fastLOGIC.kicad_pcb, fastLOGIC.kicad_sch]
2023-12-30 changed holes, vias and markings
    [fastLOGIC.kicad_pcb]
2024-01-04 minor pcb changes, image
    [bom.csv, designators.csv, fastLOGIC.kicad_pcb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]
2024-01-04 added library and example arduino firmware
2024-01-04 changed description image, added relay 2 output
2024-02-08 hardware minor mistake fixes
    [fastLOGIC.kicad_pcb, fastLOGIC.kicad_sch]
2024-02-16 Implementation of i2c to rs485 on the software side
2024-02-16 Implementation of the i2c to rs485 class
2024-02-16 Added commentary and changed print out from german to english
2024-04-09 improved schematic overview with more data added
2024-04-15 fixed relay pin mapping and added SPI connector
2024-04-18 adde led shine on description img
2024-09-03 added HW version 002, incl 3d files, PCB design
2024-12-31 hardware version 2.0 finished and sent to manufacturer
    [DG141R-10-2.54.step, DG141R-11-2.54.step, DG141R-12-2.54.step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]
2025-03-31 heap commit, not up to date changes. rest following
    [Configuration.h, fastLOGIC.kicad_pcb, fastLOGIC.kicad_sch]
